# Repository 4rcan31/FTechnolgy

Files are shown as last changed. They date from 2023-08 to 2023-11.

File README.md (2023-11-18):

# FTecnology
## _Empresa para tus mascotas_

Somos una empresa dedicada a proporcionar soluciones innovadoras para el cuidado y mantenimiento de mascotas. Nuestra primera solución destacada es **Croquette**, un dispensador de comida para mascotas que ofrece una experiencia única y conectada. Este repositorio contiene tanto información sobre el proyecto principal, FTecnology, como los detalles específicos de Croquette.

## FTecnology: Innovación en Cuidado de Mascotas (Croquette)
FTecnology es la empresa detrás de la solución Croquette. Nuestra misión es mejorar la vida de las mascotas y sus dueños a través de soluciones tecnológicas innovadoras. Estamos comprometidos con la excelencia en diseño, funcionalidad y experiencia del usuario.

# Croquette
Croquette es un dispensador de comida para mascotas que va más allá de lo convencional. Su característica principal es la capacidad de conectarse a la aplicación de FTecnology, lo que permite a los dueños de mascotas dispensar comida de manera remota a través de Internet. Esto proporciona flexibilidad y comodidad tanto para los dueños de mascotas como para las propias mascotas.
## Features

- **Conexión Remota:** Croquette se conecta a la aplicación FTecnology, lo que permite a los usuarios dispensar comida de forma remota. Ya no es necesario estar físicamente presente para alimentar a tu mascota.

- **Programación de Alimentación:** Los usuarios pueden establecer horarios de alimentación regulares para sus mascotas a través de la aplicación. Croquette dispensará automáticamente la cantidad programada de comida en los momentos designados.

- **Monitoreo en Tiempo Real:** La aplicación proporciona información en tiempo real sobre cuándo se dispensó comida por última vez, cuánta comida queda en el dispensador y el consumo de comida de tu mascota en general.

## Archivos de Diseño de Croquette
En este repositorio, encontrarás los archivos de diseño de Croquette (El dispensador) en formato .blend y .stl

# Documentación de Croquette
Si deseas ver la documentación de Croquette, haz click [aquí](/Croquette/README.md).

# Instalación

## Requisitos 
- Git.
- El comando `php` debe estar disponible en tu terminal (configura las variables de entorno en caso de usar Windows).
- PHP versión >= 7.
- MySQL debe estar instalado en tu sistema.
- El comando `mysql` debe ser accesible desde tu terminal (configura las variables de entorno en caso de Windows, o simplemente utiliza MySQL desde un gestor de bases de datos como phpMyAdmin o MySQL Workbench).
- Composer debe estar instalado (no es esencial, pero puede ser útil para la actualización de dependencias).
- Node.js es necesario para ejecutar el servidor de comunicación de Croquette.

## Recomendaciones (Solo en caso de que no estés seguro de lo que estás haciendo, o para evitar perder tiempo solucionando problemas de compatibilidad)

Una de las cosas necesarias es tener una versión de PHP igual o superior a 7. Si estás utilizando XAMPP, verifica que la versión sea la correcta, ya que XAMPP suele instalar `php v 5`. Yo recomiendo utilizar Laragon, ya que incluye una versión más actualizada de PHP y también MySQL (recuerda que debes editar la variable PATH para que los comandos `php` y `mysql` sean reconocidos). (Si no quieres hacer tanto tramite y instalar Laragon, primero verifica si tu XAMPP ya tiene una version de php mayor o igual que 7).Yo te recomendaría verificar primero tu versión de PHP antes de instalar Laragon o actualizar la versión de PHP en XAMPP.

Si deseas verificar tu versión de PHP (una vez hayas configurado la variable PATH), ejecuta:
```sh
php -v
```

No es estrictamente necesario configurar `mysql` o `php` en las variables de entorno (PATH) si no te sientes cómodo haciéndolo y si sabes lo que haces. En lugar de eso, puedes seguir estos pasos alternativos:

- **Configuración de MySQL:** Puedes utilizar la interfaz de usuario de tu gestor de bases de datos, ya sea phpMyAdmin o MySQL Workbench, para realizar el paso número 2, que implica crear la base de datos. Esto te permite hacerlo de manera gráfica y sin necesidad de configurar variables de entorno.

- **Configuración de PHP:** No es imprescindible tener PHP configurado en las variables de entorno. La única condición es que debes iniciar el servidor desde la carpeta `/public`. Esto se logra automáticamente con el comando `php jenu serve`, que ejecuta internamente `php -S 127.0.0.1:8080 -t /public`. Esta opción simplifica el proceso y no requiere ajustes complicados.

## Pasos
### 1. Clonar el repositorio
```sh
git clone https://github.com/4rcan31/FTechnology.git
```

### 2. Crear la base de datos
#### 2.1 Ingresar al gestor de base de datos
```sh
mysql -u root -p
```
El parámetro `-u` es para el usuario y `-p` para la contraseña.

#### 2.2 Crear la base de datos
```sql
CREATE DATABASE ftechnology;
```

### 3. Configurar variables de entorno (Archivo `.ENV`)

```env
DB_CONNECTION=mysql
DB_HOST=localhost
DB_PORT=3306
DB_DATABASE=ftechnology
DB_USERNAME=root
DB_PASSWORD=
```

##### Valores por defecto (generalmente no cambian)
- `DB_CONNECTION`: Gestor al que se conectará.
- `DB_HOST`: Host al que se conectará.
- `DB_PORT`: Puerto del host al que se conectará.

##### Valores que generalmente cambian
- `DB_DATABASE`: Nombre de la base de datos a la que se conectará.
- `DB_USERNAME`: Nombre de usuario para acceder al gestor de base de datos.
- `DB_PASSWORD`: Contraseña para acceder al gestor de base de datos (por defecto es vacía).

### 4. Verificar si la configuración de la base de datos fue exitosa

```sh
php jenu check:connection:mysql
```

### 5. Ejecutar las migraciones (crear tablas)

```sh
php jenu execute:migrations
```

### 6. Instalar las dependencias ejecutando
```sh
composer install
```
Este comando no es necesario (solamente para una posible actualizacion de las dependencias)

### 7. Ejecutar el servidor web
```sh
php jenu serve
```

El programa debería estar en funcionamiento en:
```sh
http://localhost:8080
```

# Instalación del Servidor Croquette

El servidor Croquette es una parte opcional de la aplicación que permite la comunicación en tiempo real con clientes de socket TCP (Croquettes). Para habilitar esta función, es necesario contar con Node.js, ya que el servidor utiliza un socket TCP implementado con la biblioteca "net" de Node.js. Este protocolo permite la comunicación bidireccional entre los clientes de socket TCP y la aplicación HTTP. A continuación, se describe el flujo de comunicación:

## Comunicación desde el Cliente de Socket TCP al Servidor Croquette (SocketServerCroquette) y la Aplicación HTTP (AppHttp)
### Cliente Socket TCP -> Socket Server Croquette -> Aplicación HTTP

1. Un cliente de socket TCP se conecta al servidor de Croquette (SocketServerCroquette).

2. El servidor de Croquette identifica la conexión como un cliente de socket TCP mediante una cabecera especial.

3. El servidor de Croquette guarda la conexión en un mapa de JavaScript asociándola con un token proporcionado por el cliente de socket TCP. El mapa se estructura de la siguiente manera:

   ```
   token -> socket
   ```

4. El servidor de Croquette realiza una solicitud HTTP (usando Axios) a la aplicación HTTP, incluyendo el token de identificación del cliente de socket TCP. Este token sirve como identificador del socket del cliente TCP para permitir la comunicación en tiempo real, ya que el socket del cliente TCP permanece activo en el mapa de conexiones.

## Comunicación desde la Aplicación HTTP (AppHttp) al Servidor de Croquette (SocketServerCroquette) y el Cliente de Socket TCP
### Aplicación HTTP -> Server Croquette -> Cliente Socket TCP

Cuando la aplicación HTTP desea enviar un mensaje al cliente de socket TCP, sigue el siguiente proceso:

1. La aplicación HTTP se conecta al servidor de Croquette TCP (SocketServerCroquette).

2. El servidor de Croquette (SocketServerCroquette) identifica si la entidad que se está conectando es la propia aplicación HTTP o un cliente de socket TCP mediante una cabecera especial.

3. Durante la misma conexión, la aplicación HTTP proporciona el token al servidor de Croquette (SocketServerCroquette) para indicar a quién se debe dirigir el mensaje.

4. El servidor de Croquette (SocketServerCroquette) verifica si el token está presente en su mapa de conexiones. Si se encuentra, se utiliza para enviar el mensaje a través del socket asociado a ese token.

Este flujo permite la comunicación en tiempo real entre la aplicación HTTP y los clientes de socket TCP a través del servidor de Croquette.

No necesitas realizar una instalación adicional, ya que las dependencias se descargaron automáticamente junto con el repositorio. Sin embargo, si deseas actualizarlas, puedes ejecutar alguno de los siguientes comandos:

Para instalar las dependencias:
```sh
npm install
```
Para actualizarlas:
```
npm update
```
Ambas opciones están disponibles para mantener tus dependencias al día.
## Ejecución del Servidor Croquette

Para iniciar el servidor Croquette, utiliza el siguiente comando:

```sh
node Server/Croquette.js
```

El servidor estará disponible en la siguiente dirección:

```sh
127.0.0.1:8081
```

Si deseas realizar pruebas, se proporciona una simulación de conexión de un Croquette que está asociado al primer Croquette Auth en la base de datos. Para iniciar la simulación de conexión, ejecuta el siguiente comando:

```sh
node Server/clienteSimulation.js 127.0.0.1 8081
```

La simulación de conexión para pruebas debería estar funcionando correctamente.

# Comandos FTecnology
FTecnology aún no cuenta con una interfaz gráfica para un panel de administración del CEO, pero sí cuenta con un CLI para ello, y hay algunos comandos que me han resultado útiles. Para ver los comandos de FTecnology, simplemente ejecuta:
```sh
php jenu help
```

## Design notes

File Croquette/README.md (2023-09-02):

# Croquette
Croquette es un dispensador de comida para mascotas que va más allá de lo convencional. Su característica principal es la capacidad de conectarse a la aplicación de FTecnology, lo que permite a los dueños de mascotas dispensar comida de manera remota a través de Internet. Esto proporciona flexibilidad y comodidad tanto para los dueños de mascotas como para las propias mascotas.
## Features

- **Conexión Remota:** Croquette se conecta a la aplicación FTecnology, lo que permite a los usuarios dispensar comida de forma remota. Ya no es necesario estar físicamente presente para alimentar a tu mascota.

- **Programación de Alimentación:** Los usuarios pueden establecer horarios de alimentación regulares para sus mascotas a través de la aplicación. Croquette dispensará automáticamente la cantidad programada de comida en los momentos designados.

- **Monitoreo en Tiempo Real:** La aplicación proporciona información en tiempo real sobre cuándo se dispensó comida por última vez, cuánta comida queda en el dispensador y el consumo de comida de tu mascota en general.

## Archivos de Diseño de Croquette
En este repositorio, encontrarás los archivos de diseño de Croquette (El dispensador) en formato .blend y .stl

### **Croquette/designs.tls/allDesing.stl  Croquette/designs.tls/allDesing.blend**
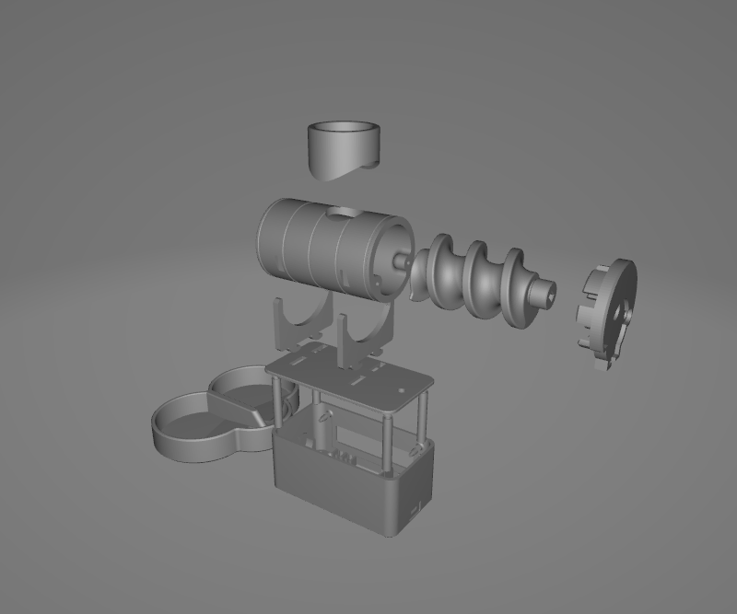
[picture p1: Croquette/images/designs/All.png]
AllDesingns


Explicación de diseño 

- **Líneas Celeste:** Explican el movimiento para ensamblar el dispensador
- **Líneas Rojas:** Las partes del dispensador
- **Líneas Verdes:** Entrada y salida de comida
- **Líneas Azules:** Dimensión de la imagen

### **Dimensión en menos X (-x)**
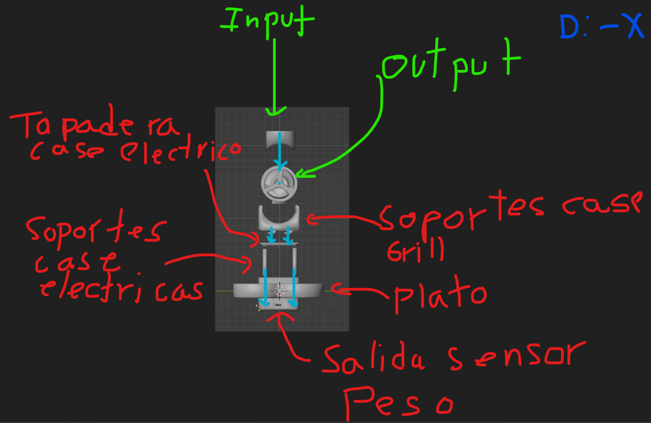
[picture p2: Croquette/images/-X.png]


### **Dimensión en X (x)**
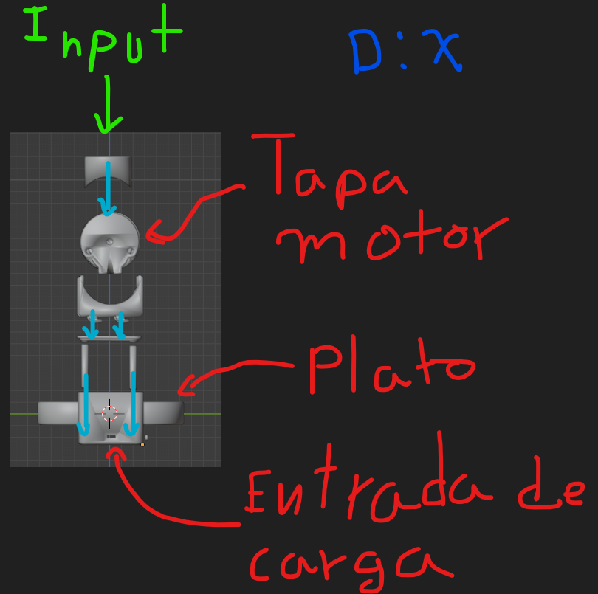
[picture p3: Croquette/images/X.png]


### **Dimensión en Y (Y)**
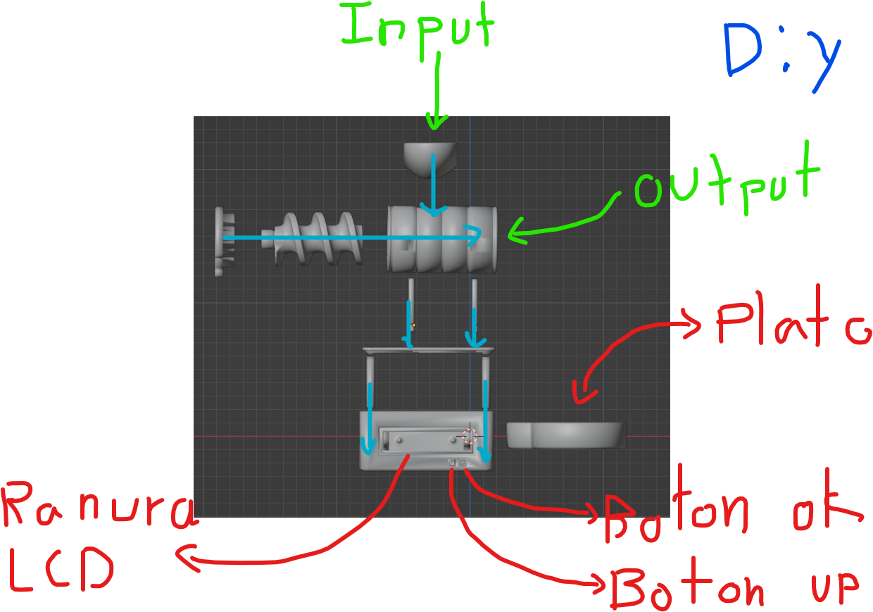
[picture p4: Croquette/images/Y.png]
ImageTechY


### **Dimensión en menos Y (-Y)**
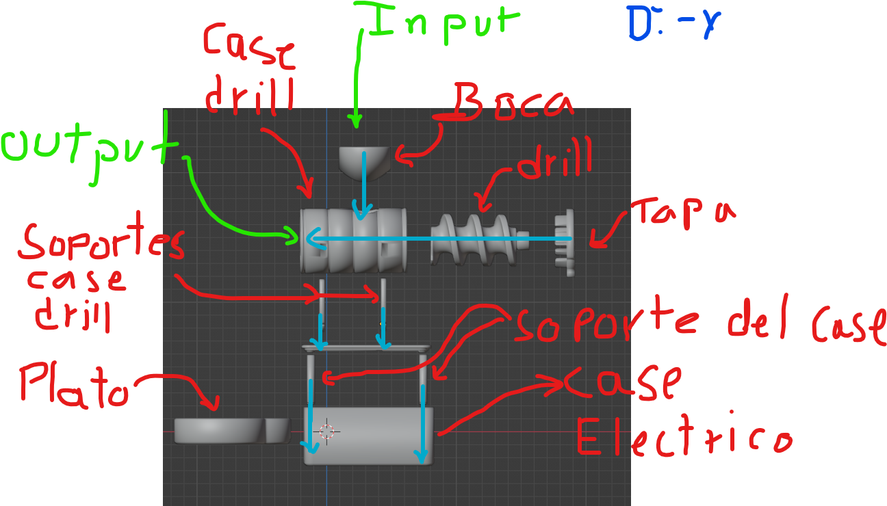
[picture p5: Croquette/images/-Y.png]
ImageTech-Y


### **Costado de todo el diseño**
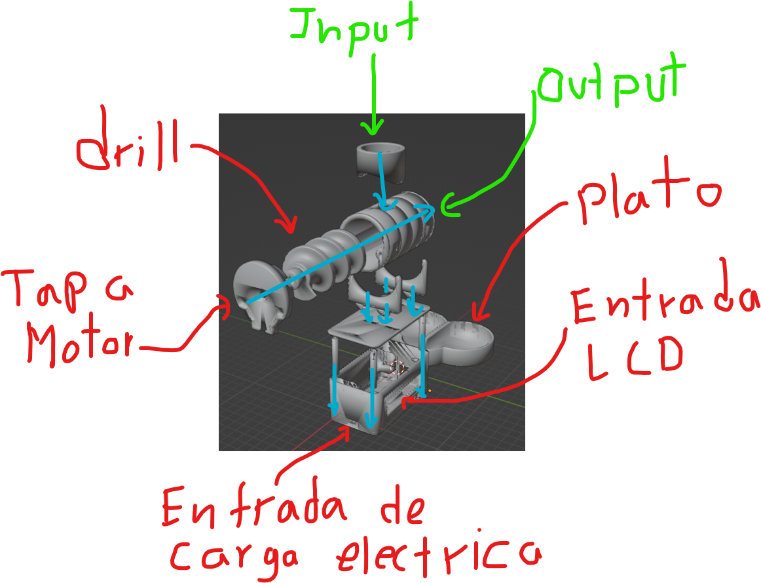
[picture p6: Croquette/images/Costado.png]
ImageTechAll

### **Case eléctrico**
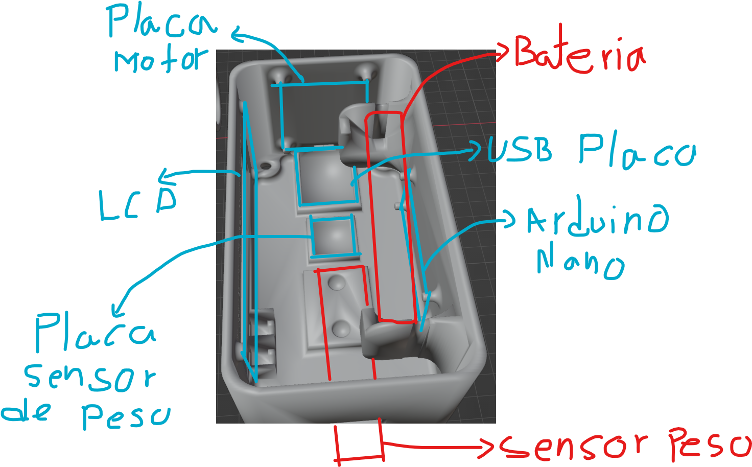
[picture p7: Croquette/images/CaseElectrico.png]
ImageTechCaseElectric


### **Soporte y botones del case**
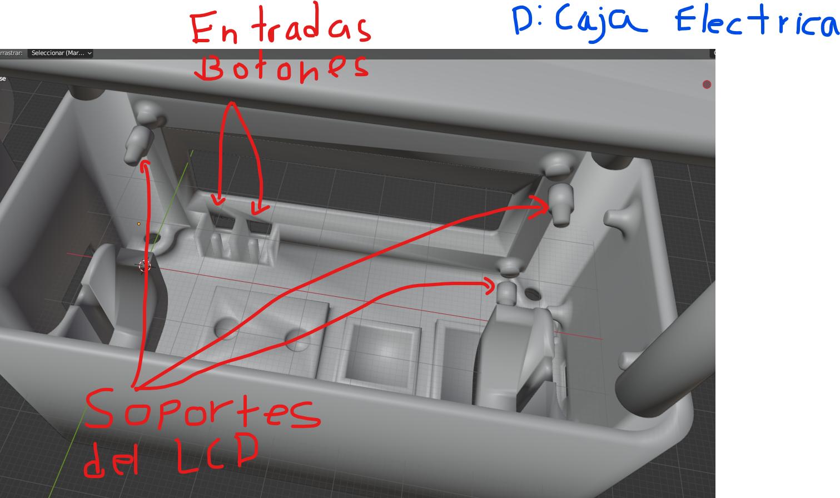
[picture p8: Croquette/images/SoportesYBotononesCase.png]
ImageTechSoporteAndButtons


## Tech

Estos son todos los archivos .tls en el proyecto para imprimir

- **Croquette/designs.tls/Button_Ok.tls** Es el botón de OK 
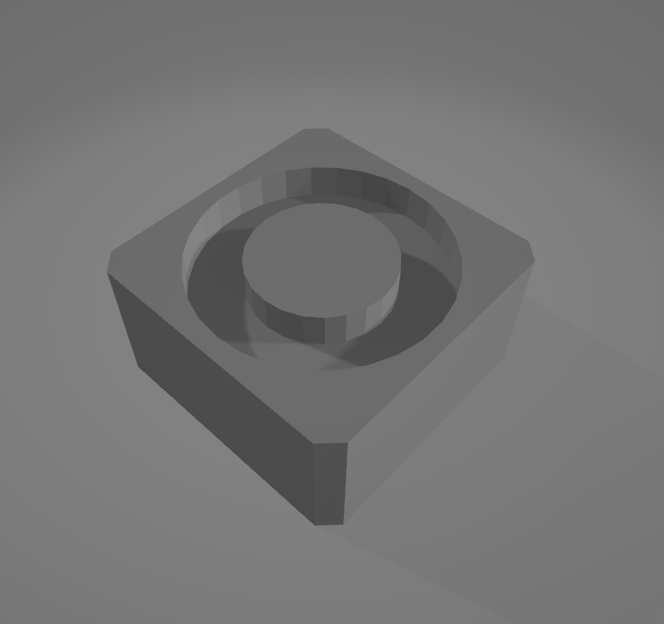
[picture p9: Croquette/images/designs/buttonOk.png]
ButtonOk

- **Croquette/designs.tls/Button_Up.tls** Es el botón para subir o bajar selecciones
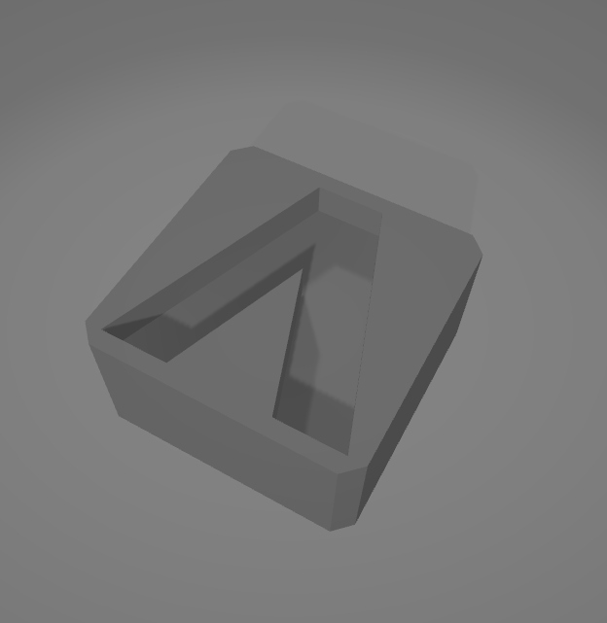
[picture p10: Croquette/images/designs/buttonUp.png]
ButtonUp

- **Croquette/designs.tls/Case_Cover_Leg.tls** Soporte de caja eléctrica (x4)
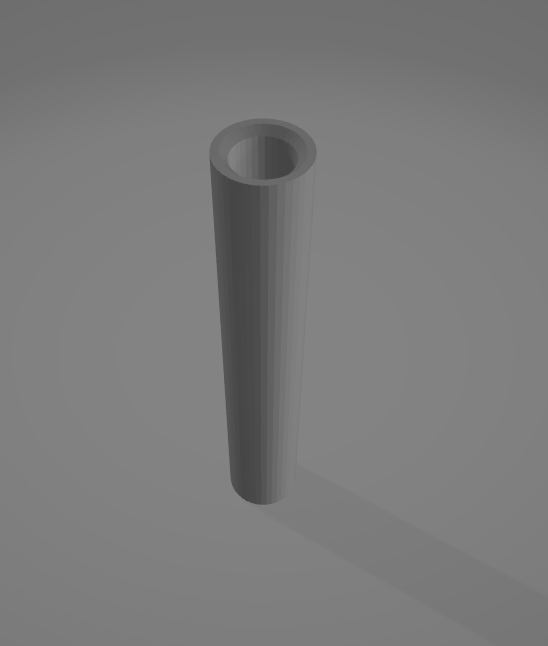
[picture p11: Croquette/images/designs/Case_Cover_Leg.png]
LegCasex4


```
Nota: El archivo Case_Cover_Leg.tls se imprimirá 4 veces, ya que son 4 soportes para la caja (en cada esquina un soporte) 
```
- **Croquette/designs.tls/Extruder_P1.tls** Este es el case para el espiral
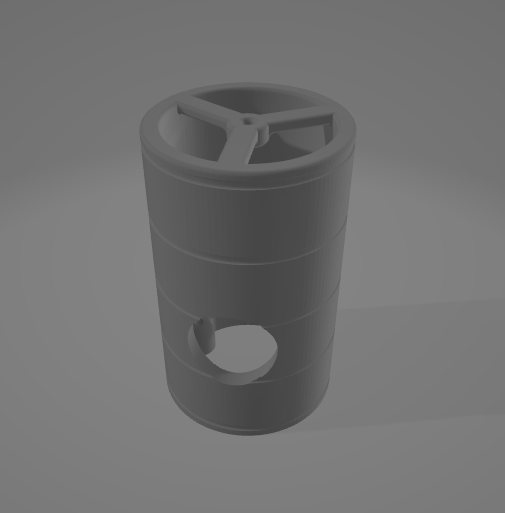
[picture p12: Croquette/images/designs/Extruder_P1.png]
CaseDrill

- **Croquette/designs.tls/Extruder_P2.tls** Esta pieza es donde entra la comida
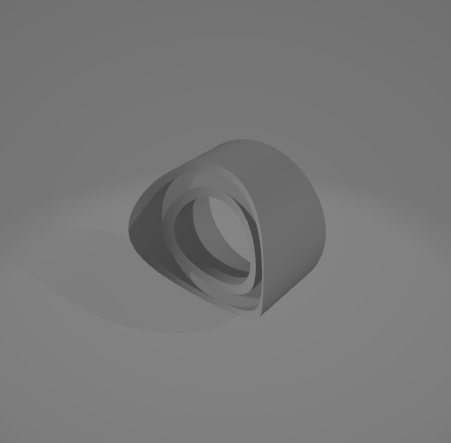
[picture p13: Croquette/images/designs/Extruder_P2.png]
TopCaseDrill

- **Croquette/designs.tls/UNO+PW_Case.tls** Este es el case eléctrico
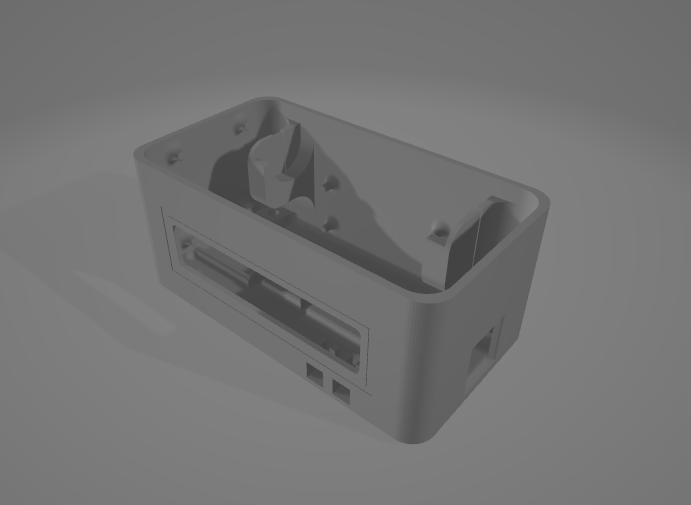
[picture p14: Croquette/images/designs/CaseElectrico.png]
CaseElectrico

- **Croquette/designs.tls/UNO+PW_Case.tls** La tapadera del case eléctrico
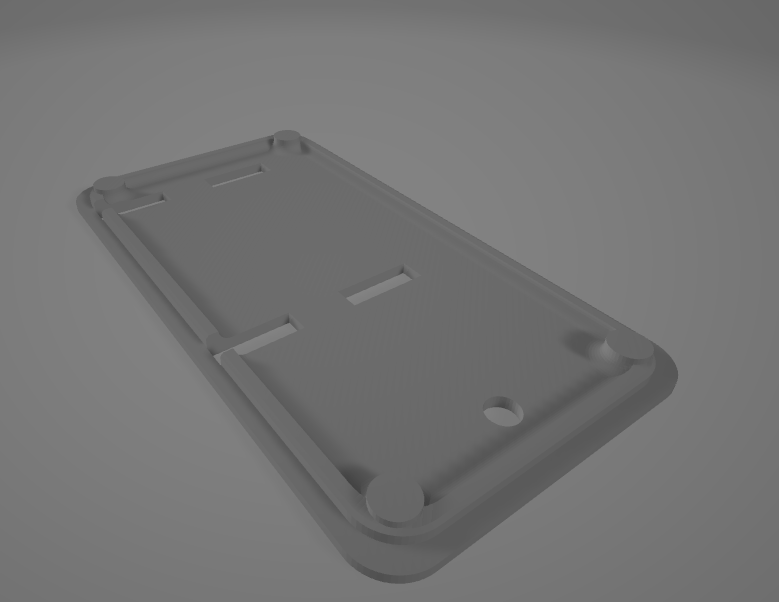
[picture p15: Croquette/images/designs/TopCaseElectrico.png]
CaseElectrico


- **Croquette/designs.tls/Tray.tls** EL plato donde se dispensara la comida
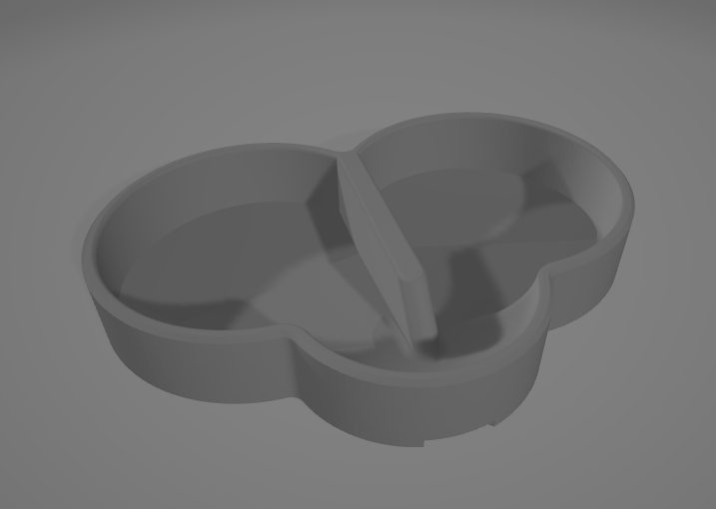
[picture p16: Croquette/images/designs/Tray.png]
Tray


- **Croquette/designs.tls/Tray_Left.tls** Plato del lado izquierdo
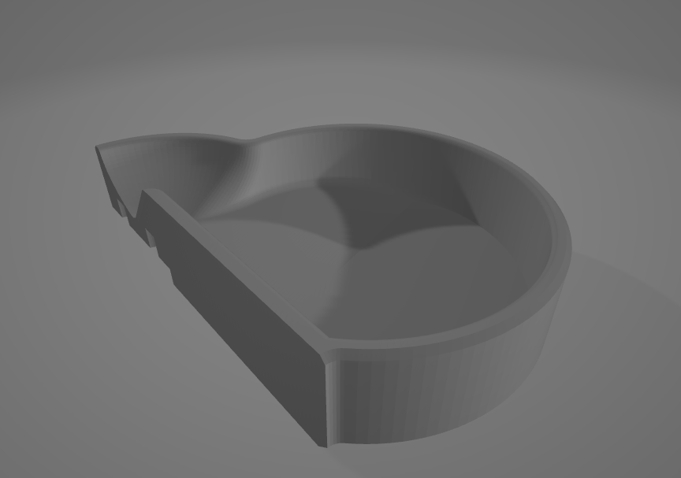
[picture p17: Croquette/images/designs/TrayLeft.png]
Tray


- **Croquette/designs.tls/Tray_Right.tls** Plato del lado Derecho
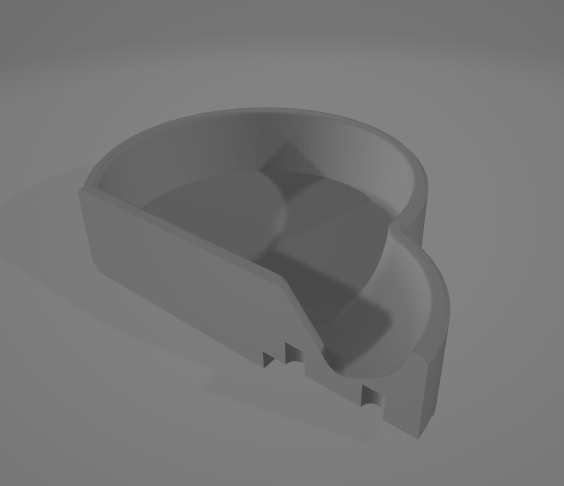
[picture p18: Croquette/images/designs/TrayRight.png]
Tray


```
Nota: Hay 3 archivos para el plato: Tray_left.tls, Tray_Right.tls & Tray.tls

Se imprimirá solo Tray.tls, ya que el de izquierda y derecha no son ensamblables
```

- **Croquette/designs.tls/LCD_Pin.tls** Pines para sostener la pantalla LCD (x3)
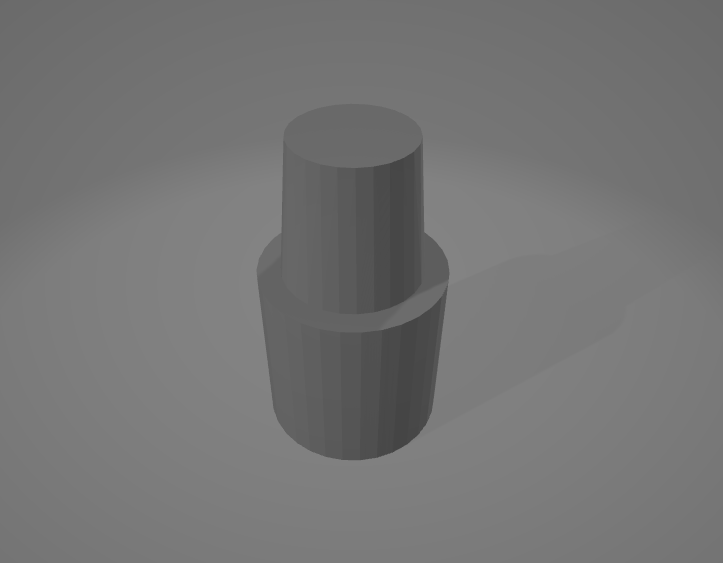
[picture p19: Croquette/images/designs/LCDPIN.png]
pinx3

```
Nota: El archivo LCD_Pin.tls se imprimirá 3 veces, ya que son 3 soportes para la pantalla LCD
```

- **Croquette/designs.tls/Motor_plate.tls** Placa para sujetar el motor y hacer girar el espiral
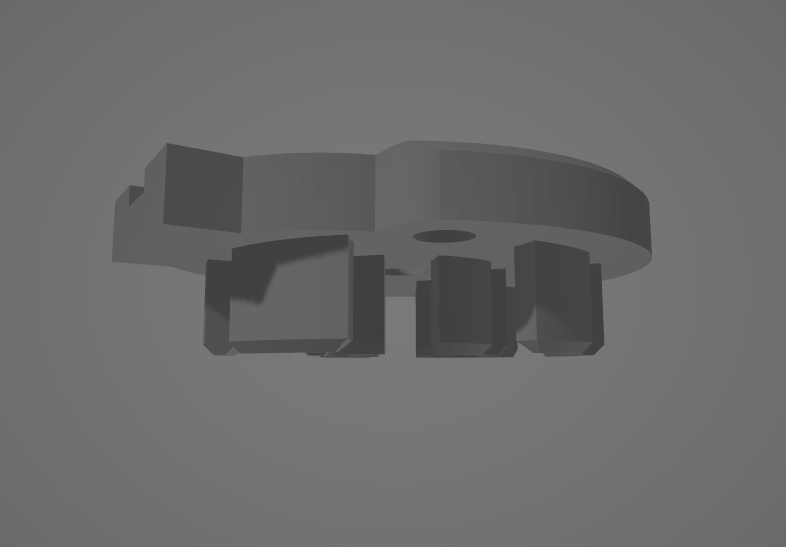
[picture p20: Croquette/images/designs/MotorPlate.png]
plateMotor


- **Croquette/designs.tls/Support_Feeder.tls** Soporte para mantener la case del espiral (x2)
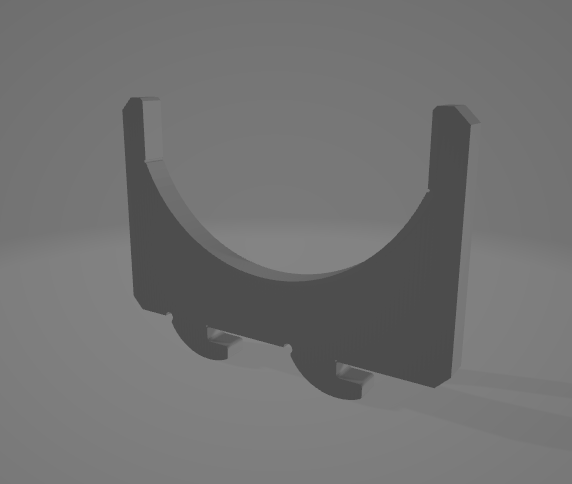
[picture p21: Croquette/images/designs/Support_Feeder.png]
SupporteCaseDrill

```
Nota: El archivo Support_Feeder.tls se imprimira 2 veces, ya que son 2 soportes para el case del espiral
```
- **Croquette/designs.tls/Wormgear.tls** Espiral normal (a imprimir)
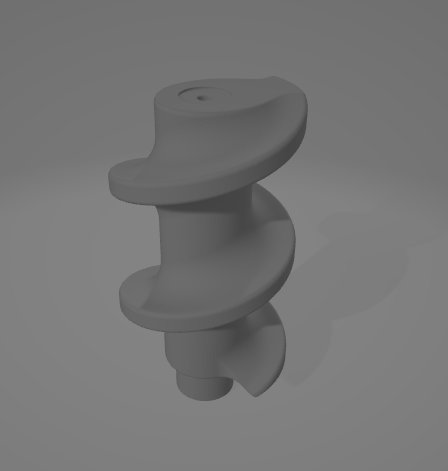
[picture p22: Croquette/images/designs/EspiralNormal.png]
DrillNormal


- **Croquette/designs.tls/Wormgear_short_pitch.tls** Espiral con un espacio mas largo 
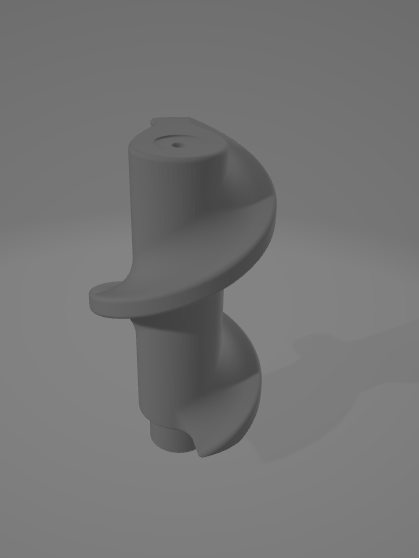
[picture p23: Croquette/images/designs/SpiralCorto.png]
DrillShort


- **Croquette/designs.tls/Wormgear_long_pitch.tls** Espiral con un espacio mas corto 
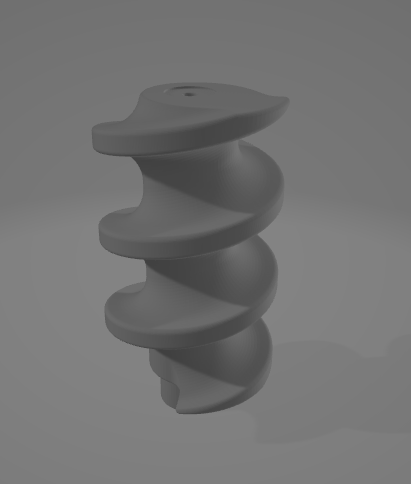
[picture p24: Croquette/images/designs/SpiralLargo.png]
DrillLong


```
Nota: Hay 3 archivos para el espiral: Wormgear.tls, Wormgear_short_pitch.tls & Wormgear_long_pitch.tls

Se imprimirá solamente uno, creería que el mas optimo es Wormgear.tls
```

### Resumen
- El archivo **Case_Cover_Leg.tls** se imprimirá 4 veces
- El archivo **Tray.tls** es el que se imprimirá 
- El archivo **LCD_Pin.tls** se imprimirá 3 veces
- El archivo **Support_Feeder.tls** se imprimirá 2 veces
- Por optimización, se imprimirá solamente el archivo **Wormgear.tls**

# Componentes electricos
- 1x Arduino Nano V3
- 1x Stepper Motor: 28BYJ-48; Driver: ULN2003A
- 1x Load Cell 1Kg with ADC HX711
- 1x LCD Display: LCD1602A
- 2x Tact button
- 1x Micro USB 1A 18650 Lithium Battery Charging Board
- 1x 18650 battery
- 1x Capacitor 330uF 35V 
- 2x M3x10 Screws (motor plate)
- 4x M4x10 Screws (case)
- 2x M4x15 Screws (load cell_tray)
- 2x M5x15 Screws (case_load cell)
- Cables

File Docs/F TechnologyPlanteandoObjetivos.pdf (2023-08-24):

Nombre del proyecto: F Technology | Fecha: Jueves 23 de febrero de 2023

Nombre de los integrantes:

1. Judith Cruz Palacios
2. Yara Stefanie Linares Hernández
3. Gabriela María Mejía Recinos
4. Gracia María González Méndez
5. Rodrigo Daniel Franco Escobar
6. Noe Antonio Molina López
- Objetivo general del Proyecto:

Desarrollar un producto que sea capaz de conectar al usuario con su mascota y brindarle cuidados alimenticios a distancia vía wifi.

- Área de Desarrollo del proyecto:
Informática
Comercio
Negocios
Bienestar animal
Hogar
- Necesidad que cubre o problema que solventa su proyecto:
Comunicación entre el dueño y su mascota.
La problemática alimentaria que se genera entorno a una necesidad básica que presente una mascota al estar solo.
- Materiales para utilizar: (hacer una tabla de cantidad, descripción, valor unitario y valor total)
Materiales | Cantidad | Valor unitario
Arduino Uno (con WiFi) | 1 | $55.00
Placa de presión | 1
Micro Servomotor MG90S | 1 | $14.98
Juego de 80 cables | 1 | $4.49
Sensor de ultrasonidos | 1 | $4.75
Filamento | 1 | $40.85
Comida para perros (usar para el prototipo) | 1 lb | $1.50
Comida para gatos (usar para el prototipo) | 1 lb | $1.50

- Público objetivo o clientes potenciales:
Personas que vivan solas, tengan mascotas y que mayor parte del tiempo estén fuera de casa.
- Descripción del funcionamiento paso a paso:
Un dispensador de comida conserva el alimento de la mascota en adecuadas condiciones. Planteado esto, el dispensador de comida contará con una programación que permite al usuario plantear periodos de tiempo en los que la comida será depositada en el recipiente a través de una aplicación y también el producto contara con un sensor en la parte inferior en donde se sirva la comida, este permitirá conocer si el plato está vacío; si detecta que no está vacío que se salte el horario siguiente pero si detecta que está vacío que llené el depósito, es decir, que el cliente podrá alimentar a su mascota sin la necesidad de estar en casa. Dicho esto, se realizaría de la siguiente manera:
- El dueño contara con una aplicación llamada F technology, donde realizara las solicitudes de registro necesarias para su ingreso en dicha App.
- Al ingresar el usuario marcara los lapsos de tiempo y raciones en los que desea que se sirva la comida.
- Dicha información será transmitida vía wifi al arduino incluido en el producto, que con la programación adecuada realizará cada una de las solicitudes propuestas.
- La comida será trasladada al recipiente por un tubo el cual tendrá una compuerta que abrirá y cerrará con la información transmitida al servomotor.
- Cuando el recipiente de alimento este vacío el arduino emitirá un mensaje a través de la aplicación al usuario. Logrando que el ciclo de alimentación se efectué de la misma manera planteada desde el punto 2.
- En el dado caso el sensor detecte que el recipiente aún no está vacío se saltará hasta el siguiente horario para servir la ración de alimento y dejará un registro en la aplicación para avisar al usuario cuando se efectuó un salto de horario.
- Diseño preliminar del proyecto (puede usar Tinkercad para ilustrarlo)



- La competencia:
- PUPPY KITTY 4L
- WellToBe
- SiSmart (Peet Feeder)
- Balimo Lena 4L
- PetKit
- Problemas encontrados:

Para la implementación del producto:
- Credencial de salubridad.
- Accesibilidad que el cliente tenga a una red. o Nivel de ingresos económicos del cliente.
- Creencias socioculturales del cliente.
- Soluciones posibles a los temas anteriores:
- Solicitud de credencial de salubridad.
- Cuando el cliente esté en el proceso de compra de producto será sometido a un cuestionario en el cual se le pregunte a cerca de la calidad de red de internet que posee
- Evaluar en base a formularios o cuestionarios el porcentaje de ingresos económicos, posteriormente moldear el producto al alcance de cada categoría socioeconómica.
- Realizar producciones beta o evidencias en exposición sobre el funcionamiento del producto.
- Necesidades futuras para el logro de concreción:

- Ingresos económicos
- Producción
- Línea de tiempo hasta el tercer periodo:

### 1. Buscar problemas en nuestra realidad o entorno

### 2. Lluvia de ideas para crear soluciones a los problemas encontrados haciendo uso de

arduino y el uso de la impresora 3D

### 3. Escogiendo ideas y analizarlas a fondo (aplicarles el FODA, el mapa de empatía y el

PEST)

### 4. Creando ideas para el logo y nombre del emprendimiento

### 5. Concretar a fondo cuales son las funciones que queremos que el producto realice 6. Comenzar con la creación de las primeras pantallas de la aplicación para el control

del producto (SplashScreen, Login, Menú)

### 7. Probando ideas para carcasa del producto y para poner la ubicación de la placa de

arduino
2 8. Hacer listado de materiales que se necesitan para crear la carcasa del producto
9. Empezar con la programación del producto por medio de C++
P 10. Desarrollo más a fondo de la programación de las pantallas de la aplicación
11. Creación del primer prototipo
12. Detectar posibles fallas.
13. Análisis de posibles mejoras a implementar.
14. Iniciar diseño de carcasa en impresora 3D.

1

P

3

P

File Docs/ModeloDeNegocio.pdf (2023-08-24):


# MODELO DE NEGOCIO FTECNOLOGY

## Contenido

Situación problemática | 2
Propuesta de negocio | 2
Modelo canvas | 4
Segmento de mercado | 5
Los jóvenes adultos (22-25) / demográfico | 5
Familia con hijos adolescentes / psicográfico | 5
Canales de distribución (tabla) | 0
Propuesta de valor | 0
Perfil del cliente | 0
Perfil de la empresa | 0
Presupuesto | 1
Producto material | 1
Presupuesto aplicación | 1
Integrantes | 2
Código de honor | 2

## Situación problemática

En la actualidad son con demasía los trabajos que requieren un mayor aporte presencial, por lo que la mayoría de la población salvadoreña invierte largos periodos de tiempo, muchas de estas personas involucradas han creado un lazo afectivo con sus fieles mascotas, brindándoles cariño y cuidados básicos que estos animales demanden. La responsabilidad, el compromiso, la lealtad y el amor incondicional forman parte de un vínculo afectivo que el dueño tiende a hacer con su mascota, por consecuencia se genera una empatía animal donde el individuo querrá brindarle cariño y cuidados básicos u específicos para el sano desarrollo y cuidado de su mascota.

En nuestro país existen muchas personas poseedoras de mascotas que pasan lejos de sus casas durante largos períodos de tiempo ya sea por factores académicos o laborales que demanden su presencia, por lo tanto, sus mascotas quedan solas en casa sin un control en su entrega diaria de alimento; debido a esto los dueños idean posibles soluciones como pedirle a un vecino o persona de confianza que pueda cuidarlo mientras no esté, cancelar o posponer salidas, dejar raciones dobles, etc., algunas de estas soluciones llegan a generar un desbalance en la ingesta de alimentos, por lo que, a largo plazo desarrollarían problemas de salud (vomito, sobrepeso, diarrea etc.), llegando a afectar así un desarrollo adecuado más, sin embargo, la mascota no es la única que tiene problemas en esta situación, al amo o dueño puede pasar por momentos de estrés o preocupación.

## Propuesta de negocio

Un dispensador de comida conserva el alimento de la mascota en adecuadas condiciones es por esto que F Technology con su producto Croquette planea funcionar como un dispensador de comida para mascotas que ayudará al cliente a organizar y/o crear horarios de alimentación para su mascota de forma remota. Pero indagaremos más en esto continuación.

Muchas personas tienen mascotas, solo en El Salvador, el 65% de la población admite tener al menos una mascota (predominando perros y gatos); a su vez, dentro de este gran porcentaje de personas con mascotas se encuentra un grupo que no tiene tiempo (ya sea porque estudia, trabaja o realizaba ambas actividades) que dedicarles a sus mascotas, en especial a uno de los puntos más importantes del cuido de una “la alimentación”. De este problema ya se han intentado encargar otros productos como “Smell n Smile”, “Ferplast”, entre otros; pero todos estos fallan en algo, su funcionamiento, pues sirven comida de forma “constante” o tras presionar un botón colocado en el dispensador, por lo tanto, una persona que no se encuentra cerca de dicho dispositivo y por ende de su mascota, no puede llevar registro de las porciones que esta come.

Ahora la pregunto es, ¿cómo Croquette resuelve este problema? Bien, conocemos el problema y sabemos que no todas las mascotas son iguales o comen la misma cantidad de alimento, es por esto que nuestro producto funciona como un dispensador de comida, pero lo que caracteriza a Croquette es que no es un dispensador de comida cualquiera, Croquette permite al usuario programar la hora y tamaño de porción que se servirá y todo esto de forma remota, haciendo uso de una aplicación móvil llamada FTechnology que es amigable al usuario y realmente intuitiva, todo esto permite llevar control de la alimentación de la mascota.

El objetivo del producto no es solo ser comprado, sino funcionar como servicio; esto gracias a la aplicación móvil (indispensable para el uso del dispositivo), ¿por qué hablamos de un servicio? Bien, primero se debe saber que dentro de esta app se planea generar ingresos mediante publicidad, dicha publicidad podrá ser bloqueada por el usuario tras pagar una cuota mensual, trimestral o anual, además de que el simple hecho de poseer la aplicación le dará acceso a cualquier actualización de la misma. Así que el objetivo del producto es ser comprado, pero hacer que el usuario no se separe de la compañía.

Ahora bien, ¿cómo funciona Croquette? El dispensador de comida contará con una programación que permite al usuario plantear periodos de tiempo en los que la comida será depositada en el recipiente a través de una aplicación, asimismo el producto contará con un sensor en la parte inferior del plato de comida, este permitirá conocer si el plato está vacío o no; los materiales del dispensador son aluminio (el recipiente de comida) y plástico (la carcasa del producto).

Dicho esto, se realizaría de la siguiente manera:

- El dueño contará con una aplicación llamada “F Technology”, donde realizará las solicitudes de registro necesarias para su ingreso en dicha App.
- Al ingresar el usuario marcará los lapsos de tiempo y raciones en los que desea que se sirva la comida.
- Dicha información será transmitida vía wifi al Arduino incluido en el producto, que con la programación adecuada ejecutará cada una de las solicitudes propuestas.
- La comida será trasladada al recipiente por un tubo, el cual tendrá una compuerta que abrirá y cerrará con la información transmitida al servomotor.
- Cuando el recipiente de alimento este vacío, el Arduino emitirá un mensaje a través de la aplicación al usuario. Logrando que el ciclo de alimentación se efectúe de la misma manera planteada desde el punto 2.
- En el dado caso el sensor detecté que el recipiente aún no está vacío, se saltará hasta el siguiente horario para servir la ración de alimento y dejará un registro en la aplicación para avisar al usuario cuando se efectuó un salto de horario

Para cerrar, Croquette es un producto que busca resolver una problemática que aqueja a un público muy amplio (como lo es el de personas con mascotas, pero poco tiempo libre) es por ello y porque sobresale y diferencia de otros muchos productos que buscan lo mismo, Croquette que es un producto viable para desarrollar y que no solo generara ingresos, sino ganancias.

## Modelo canvas


## Segmento de mercado

### Los jóvenes adultos (22-25) / demográfico

Porque son ellos quienes están más tiempo fuera de casa por diversas actividades, y por consecuencia no les dedican el debido tiempo a sus mascotas.

Ejemplo de este segmento sería Pedro

- 25 años
- Soltero
- Clase socioeconómica media
- Posee 2 mascotas (1 gato y 1 pitbull)
- Universitario con trabajo de medio tiempo
- Soltero
- Reside en la zona oriental, departamento de San Miguel
- Unas de sus mayores aficiones es leer libros y hacer escritos
- Métodos de compra habituales, por lo que tiende a adquirir productos personales y de cuidados para su mascota mediante redes sociales, especialmente Instagram

### Familia con hijos adolescentes / psicográfico

Mayormente en una familia con hijos (adolescentes) son quienes están y comparten mayor tiempo con las mascotas, ya que poseen mayor disponibilidad de tiempo, por lo que se genera un vínculo afectivo entre ellos.

Quienes poseen y administran los ingresos de la familia y gastos que sus hijos requieran son los padres o tutores.

Ejemplo de este segmento sería una familia de 3 integrantes

- Steven, padre de 43 años, contador
- Paola, madre de 39 años, maestra
- María, hija de 17 años, estudiante

Que poseen las siguientes características

- Clase socioeconómica media
- Poseen un perro mestizo
- Residen en la zona central, departamento San Salvador
- Una de las aficiones de la familia es compartir tiempo con los demás integrantes de su familia, por lo que en periodos de vacación realizan reuniones familiares en otros departamentos por periodos de tiempo medio.
- Los padres usualmente visitan tiendas por recomendaciones
- La hija tiende a cotizar productos en línea

## Canales de distribución (tabla)


## Propuesta de valor

### Perfil del cliente

- Actividades
- Alimentar una mascota
- Encontrar tiempo para alimentar una mascota.
- Encontrar una persona que alimente a una mascota cuando no se está en casa.
- Dolor
- Gastar dinero para alimentar una mascota (la acción de servir comida, se obvia el gasto en *comida*)
- Usar tiempo libre para alimentar una mascota.
- Ganancias
- Mascota feliz :)
- Dueño de mascota feliz :)
- Dinero y tiempo ahorrado (porque se hace una sola inversión)

### Perfil de la empresa

- Productos y servicios
- Dispensador de comida regulable.
- App para regular un dispensador de comida para mascotas.
- Aliviador de dificultades
- Manejo a larga distancia por medio de Internet.
- App dinámica y fácil de entender y manejar.
- Programación de horarios para servir la comida.
- Avisos cuando ya esté apunto d acabarse la comida y cuando se salta una ración de comida
- Ganancia
- Aliviado por saber que su mascota se alimenta bien.
- Felicidad por que la aplicación no es difícil de usar.
- Bienestar alimenticio de su mascota.
- Tener seguridad de que su mascota poseerá sus alimentos cuando se requiera
- Ahorrar tiempo en servirle la comida a su mascota
- Economizar la cantidad de concentrado que consume su mascota

## Presupuesto

### Producto material

### Presupuesto aplicación

Materiales | Cantidad | Valor
Hosting (servidor) | 1 | $3 por mes
Materiales Materiales | Cantidad Cantidad | Valor unitario Valor unitario
Arduino Uno (con Wifi) Arduino Uno (con Wifi) | 1 1 | $55.00 $55.00
Placa de presión/ piezoeléctrico/sensor HX711/ Placa de presión/ piezoeléctrico/sensor HX711/ sensor de fuerza MF01 sensor de fuerza MF01 | 1 1 | $44.98/$3.99/$4.99/$8.89 $44.98/$3.99/$4.99/$8.89
Micro Servomotor MG90S/ Motor CC Micro Servomotor MG90S/ Motor CC | 2 2 | $14.98/$10.56 $14.98/$10.56
Juego de 80 cables Juego de 80 cables | 1 1 | $4.49 $4.49
Sensor de ultrasonidos Sensor de ultrasonidos | 1 1 | $4.75 $4.75
Filamento Filamento | 1 1 | $40.85 $40.85
Comida para gatos (usar para el prototipo) | 1 lb | $1.50
Juego de 40 ventosas de plástico con 4 diámetros: 0.787 in, 1.181 in, 1.575 in, 1.969 in | 1 | $12.77
Display LCD 16 x 2 | 1 | $5.54
Potenciómetro | 1 | $0.52
Resistencias de 330 Ohmios | 2 | $0.35
Resistencia de 4.70 Kohmios | 1 | $0.19
Transistor | 1 | $0.23
Batería de 9 voltios recargable | 1 | $6.50

## Integrantes

1. Judith Cruz Palacios
2. Yara Stefanie Linares Hernández
3. Gabriela María Mejía Recinos
4. Gracia María González Méndez
5. Rodrigo Daniel Franco Escobar
6. Noé Antonio Molina López

## Código de honor

" I have not given or received any kind of unauthorized aid."

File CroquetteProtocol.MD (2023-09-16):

# Croquette Protocol

Este es un nuevo protocolo para conecctarse

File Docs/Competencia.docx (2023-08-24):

COMPETENCIA

ARF Pets

Arf Pets es una empresa que se especializa en productos y accesorios para mascotas. Ofrecen una amplia gama de productos que incluyen camas para mascotas, jaulas, puertas para mascotas, juguetes interactivos y dispensadores de alimentos, entre otros.

Descripción: Uno de los productos más populares de Arf Pets es su línea de alimentadores automáticos para mascotas. Estos alimentadores permiten programar y controlar las porciones de comida que se sirven a las mascotas, lo que resulta útil para mantener una dieta regular y controlada. Algunos de los alimentadores también cuentan con funciones adicionales, como grabar mensajes de voz para llamar a las mascotas a la hora de comer.

Precio: 60$

Función: Hasta 4 comidas programables (también el tamaño de las mismas), grabadora de voz y alarma al servir, funciona con baterías o mediante CD

Segmento de mercado: Adultos y jóvenes adultos, Arf Pets utiliza diversos canales de redes sociales, como Twitter, Facebook e Instagram, para interactuar con su audiencia. En estas plataformas, realizan sorteos y concursos, brindando la oportunidad a los seguidores de ganar premios. Además, publican contenido relevante y entretenido, como memes y tendencias de moda, que resuenan especialmente entre el público joven y adulto. Así mismo, ARFPets se dirige a propietarios de mascotas que buscan productos de alta calidad y confianza para el cuidado y bienestar de sus animales.

¿Por qué ARFPets es nuestra competencia?

ARFPets es una competencia debido a su enfoque en la calidad de los productos que ofrecen, a la variedad de su oferta, su enfoque en la comodidad y calidad de vida, así como su reputación y confianza ganada entre los propietarios de mascotas.

Petlibro

Petlibro es una marca especializada en productos y tecnología para mascotas. Se enfocan en crear productos innovadores y de alta calidad para mejorar la vida y el bienestar de las mascotas y sus dueños.

Descripción: Uno de los productos destacados de Petlibro es su línea de comederos automáticos para mascotas. Estos comederos cuentan con características avanzadas, como programación de horarios de alimentación, porciones controladas y alimentación precisa. Los comederos automáticos de Petlibro ofrecen conveniencia y ayudan a mantener una dieta saludable y regular para las mascotas.

Precio: $51.99 a $159.99

Segmento de mercado: Petlibro tiene como objetivo principal atraer a los jóvenes y los millennials, quienes son altamente activos en la participación de sorteos y regalos a través de aplicaciones populares entre los jóvenes adultos y la Generación Z. Esta estrategia les permite promocionar tanto su marca como sus productos de manera efectiva. Además, Petlibro también se dirige a propietarios de mascotas que buscan soluciones innovadoras y tecnológicas para el cuidado y el bienestar de sus compañeros.

¿Por qué Petlibro es nuestra competencia?

Petlibro es una competencia debido a su enfoque en la innovación tecnológica, en la calidad de sus productos, a su enfoque en la salud y el bienestar de las mascotas, y la atención que brindan al cliente. Estos factores les permiten posicionarse como una opción atractiva para los propietarios de mascotas que buscan soluciones modernas y confiables para el cuidado de sus compañeros.

WORPET

WOPET es una marca que se especializa en la fabricación de productos y tecnología para mascotas, con un enfoque particular en alimentación automatizada y cuidado de mascotas.

Descripción: Uno de los productos más destacados de WOPET es su línea de comederos automáticos para mascotas. Estos comederos cuentan con funciones avanzadas, como programación de horarios de alimentación, porciones controladas y alimentación precisa. Algunos modelos incluso tienen capacidad de grabación de voz para llamar a las mascotas a la hora de comer. Estos comederos automáticos brindan comodidad y ayudan a mantener una dieta regular y equilibrada para las mascotas.

Precio: 60$

Función: se puede programar hora y tamaño de porciones, con un máximo de 6 raciones programables, además, contiene una grabadora de voz para luego usar una bocina, de esta forma se pueden dejar mensajes a las mascotas (10 segundos)

Segmento de mercado: Adultos propietarios de mascotas que buscan soluciones tecnológicas y automatizadas, WOPET se dirige a su público objetivo a través de canales estratégicos, como Facebook, reconociendo que esta plataforma es mayormente utilizada por adultos. Aprovechan este medio para darse a conocer y conectar con su audiencia. WORPET se dirige a un segmento de mercado que busca soluciones tecnológicas y prácticas para el cuidado de sus mascotas. Sus productos automatizados ofrecen comodidad, conveniencia y contribuyen al bienestar de las mascotas, satisfaciendo las necesidades y deseos de los propietarios modernos.

¿Por qué WORPET es nuestra competencia?

WOPET es una competencia para las nuevas marcas dirigidas a las mascotas debido a su reconocimiento de marca, experiencia en el mercado, por su gama de productos establecida y satisfacción brindada al cliente.

FTECHNOLOGY

Descripción

Croquette es una herramienta indispensable para aquellos que pasan mucho tiempo lejos de casa y tienen mascotas. Se trata de un dispensador de comida controlado a larga distancia que te permite programar horarios alimenticios, recibir notificaciones sobre la cantidad de comida servida y llevar un control automático de las porciones para tu mascota, todo desde la comodidad de una aplicación móvil. Con Croquette, puedes estar tranquilo sabiendo que tus fieles amigos siempre serán alimentados adecuadamente, ya que solo necesitas llenar el dispensador y dejar que Croquette se encargue del resto del día.

¿Cómo se destaca?

Para aquellos propietarios de mascotas que se enfrentan al desafío de estar lejos de casa durante largos períodos sin poder alimentar a sus compañeros de manera personal. Consciente de esta problemática, FTECHNOLOGY presenta "Croquette", un innovador dispensador de comida para mascotas controlado a través de Internet. Este dispositivo viene a satisfacer esa necesidad al garantizar que las mascotas reciban alimentación adecuada incluso en ausencia de sus dueños.

¿Qué diferencia a Croquette de la competencia?

A diferencia de otros dispensadores existentes en el mercado que utilizan cables USB, baterías o conexiones de red WiFi, Croquette va más allá al ser controlado a través de una aplicación conectada a Internet. Esta innovadora función permite establecer una conexión entre el propietario y su mascota, incluso a larga distancia, logrando así una conexión cercana y brindando tranquilidad al dueño sabiendo que puede cuidar y alimentar a su mascota sin importar dónde se encuentre.

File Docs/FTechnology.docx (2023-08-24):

FTechnolgy

Dispensador de comida para mascotas, controlado a distancia mediante una aplicación.

Integrantes

1. Gabriela María Mejía Recinos
2. Gracia María Gonzáles Méndez
3. Judith Cruz Palacios
4. Keren Abigail Guerrero López
5. Noé Antonio Molina López
6. Rodrigo Daniel Franco Escobar
7. Yara Stefanie Linares Hernández


“We have neither given nor received any unauthorized aid.”

Vista previa del formulario – Registrarse -


Vista preliminar del formulario – Registrarse -


Este formulario tiene como objetivo recopilar la información proporcionada por el usuario durante el proceso de registro. Utilizamos los siguientes elementos:

- Etiquetas (Labels) para identificar los campos a completar.
- Campos de texto (TextBox) para que el usuario ingrese sus respuestas.
- Un botón denominado "Registrarse" para confirmar, guardar y enviar la información solicitada.

Los datos recopilados se enviarán para su almacenamiento en una base de datos. Utilizamos Php para conectarnos a una base de datos conocida como MariaDB (anteriormente MySQL). Esta base de datos relacional (SQL) nos permite guardar datos en tablas con el objetivo de almacenar la información adquirida y preservarla para su uso en el futuro. Si el usuario ha mantenido una cuenta activa con FTechnology, puede acceder al formulario correspondiente haciendo clic en el texto resaltado en azul que dice "Iniciar Sesión".

Vista previa del formulario – Iniciar Sesión -


Vista preliminar del formulario – Iniciar Sesión -

Este formulario tiene como finalidad capturar la información que los usuarios ingresan durante el proceso de inicio de sesión en la página de FTechnology. Para lograrlo, se emplean los siguientes componentes:

- Etiquetas (Labels) para identificar los campos que deben completarse.
- Campos de texto (TextBox) que permiten a los usuarios ingresar sus respuestas.
- Un botón denominado "Iniciar Sesión" que cumple la función de confirmar, guardar y enviar la información proporcionada.

La información recopilada se enviará y almacenará en una base de datos. Utilizamos Php para establecer conexión con una base de datos llamada MariaDB (previamente conocida como MySQL). MariaDB es una base de datos relacional (SQL) que nos permite organizar los datos en tablas, con el propósito de preservar la información adquirida y mantenerla para su uso en el futuro. Si el usuario no recuerda haber mantenido una cuenta activa con FTechnology al intentar iniciar sesión, puede acceder al formulario correspondiente haciendo clic en el texto resaltado en azul que dice "Regístrate".

Vista previa del formulario – Contacto -


Vista preliminar del formulario – Contacto -


Este formulario tiene como objetivo recopilar la información que los usuarios ingresan al desear resolver inquietudes relacionadas con nuestros servicios y detalles de los productos. Para lograr esto, emplea los siguientes elementos:

- Etiquetas (Labels) para identificar los campos que deben ser completados.
- Campos de texto (TextBox) que permiten a los usuarios ingresar sus respuestas.
- Un botón denominado "Enviar" que tiene la función de confirmar y remitir las preguntas escritas por el usuario al correo oficial de la empresa.

La información recopilada se remitirá al correo oficial de FTechnology con el propósito de facilitar y mejorar la comunicación entre los usuarios y nuestros servicios.

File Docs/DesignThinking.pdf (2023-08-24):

# “Design Thinking”

Oportunidades, Fundacion Gloria de Kriete Emprendimiento P1
Ana Lucia Trinidad Gómez

Integrantes:
1. Judith Cruz Palacios
2. Yara Stefanie Linares Hernandez
3. Gracias María Gonzalez Mendez
4. Gabriela María Mejía Recinos
5. Rodrigo Daniel Franco Escobar
6. Noe Antonio Molina López

F Technology

Un dispensador de comida conserva el alimento de la mascota en adecuadas condiciones. Planteado esto, el dispensador de comida contará con una programación que permite al usuario plantear periodos de tiempo en los que la comida será depositada en el recipiente a través de una aplicación y también el producto contará con un sensor en la parte inferior en donde se sirva la comida, este permitirá conocer si el plato está vacío; si detecta que no está vacío que se salte el horario siguiente pero si detecta que está vacío que llené el depósito, es decir, que el cliente podrá alimentar a su mascota sin la necesidad de estar en casa. Dicho esto, se realizaría de la siguiente manera:
- El dueño contará con una aplicación llamada F technology, donde realizará las solicitudes de registro necesarias para su ingreso en dicha App.
- Al ingresar el usuario marcará los lapsos de tiempo y raciones en los que desea que se sirva la comida.
- Dicha información será transmitida vía wifi al arduino incluido en el producto, que con la programación adecuada realizará cada una de las solicitudes propuestas.
- La comida será trasladada al recipiente por un tubo el cual tendrá una compuerta que abrirá y cerrará con la información transmitida al servomotor.
- Cuando el recipiente de alimento esté vacío el arduino emitirá un mensaje a través de la aplicación al usuario. Logrando que el ciclo de alimentación se efectúe de la misma manera planteada desde el punto 2.
- En el dado caso el sensor detecte que el recipiente aún no está vacío se saltará hasta el siguiente horario para servir la ración de alimento y dejará un registro en la aplicación para avisar al usuario cuando se efectuó un salto de horario.

## DESIGN THINKING


### EMPATÍA

Mapa de empatía

Encuesta en Google Forms

https://docs.google.com/forms/d/e/1FAIpQLSdsR3Eo4c-o5tioHNsDi9w44DIcPA20TuHQPK5bVmClkoVxvA/viewf orm (https://docs.google.com/forms/d/e/1FAIpQLSdsR3Eo4c-o5tioHNsDi9w44DIcPA20TuHQPK5bVmClkoVxvA/viewform)



### DEFINICIÓN

Áreas de problemática y necesidades del cliente:

Darles de comer
1. Material del plato de comida (plástico, cerámica o metal)
2. Calidad de la comida
3. Obtención del alimento (precio, tipo y lugar de la compra)
4. Cuando la mascota come bota las croquetas del recipiente, es decir, le da vuelta al plato lo que provoca un desperdicio de comida.

Bañarlos
5. Ingredientes del producto de aseo (que no contengan químicos que pueden generar alergias o irritación)
6. Espacio adecuado para bañarlo, ya que algunos de los encuestados mencionaron que bañaban a sus mascotas en su patio esto generaba un desorden y, en algunos casos, lodo.

Dormirlos
7. Propietario de un espacio para dormir a la mascota, es decir, una cama.
8. Material o textura de las camas para mascotas.
9. Diseños originales

Control médico
10. Organización de un control de vacunas
11. Agenda de las citas al veterinario

### IDEAS

Debido a la encuesta realizada a el posible segmento de mercado, nos dimos cuenta que la problemática que más presentan los clientes es con respecto a la alimentación de sus mascotas, por lo tanto, decidimos centrar la lluvia de ideas en esa problemática.

1. Poner guardería para mascotas
2. Niñera de mascotas
3. Mini robot de comida
4. No tener mascotas
5. Dejarle doble ración de comida a la mascota
6. Salirse del trabajo para ir a darle alimento a la mascota
7. Dispensador de comidas de mascotas
8. Crear un plato con 4 divisiones las cuales se les abra la tapadera de acuerdo a la hora del día en que la mascota deba comer
9. Crear un área recreativa y de cuidado de mascotas en los lugares de trabajo de las personas
10. Entrenar a las mascotas para poder activar un botón que le brindará la comida cuando lo necesite
11. La creación de una máquina que cree materia comestible de concentrado de mascotas en base a desechos orgánicos

### PROTOTIPO


Descripción de su funcionamiento:


En este podemos observar el dispensador de comida en su totalidad, el embudo que dirige la comida hacía el plato y el mecanismo de bloqueo que se encuentra afuera del dispensador.

A la derecha podemos encontrar el mecanismo de bloqueo del dispensador. Este mecanismo hace uso de un motor cc, que al girar crea fricción con una banda en la puerta, haciendo que se mueva. Esta puerta se encuentra sostenida por dos rieles, que existen para mantener en su lugar la puerta y de esta forma evitar que caiga al suelo.

Arriba podemos ver el espacio de comida, el plato se encuentra debajo de la boca del embudo; es una cavidad rectangular con un sensor de fuerza MF01 cuya función es registrar fuerza. En este lugar, dentro de esta cavidad se coloca el plato, para que de esta forma al vaciarse/llenarse el sensor de fuerza MF01 registre los datos y los envié al arduino; consiguiendo así servir las porciones que el usuario quiere.

Se debe mencionar que debajo del embudo, es donde iría el arduino/placa, de ahí se alienta el motor cc, el sensor de fuerza MF01 y el display LCD 16 x 2.

### TESTEAR / EVALUAR

Cuestionario
Formulario de google forms https://docs.google.com/forms/d/e/1FAIpQLSfYyHOxj9HiPvgDpm4e4QaK-KA3dM1SS_z9t49oj9j6lJuWrw/viewform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 (https://docs.google.com/forms/d/e/1FAIpQLSfYyHOxj9HiPvgDpm4e4QaK-KA3dM1SS_z9t49oj9j6lJuWrw/viewform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)

Encuesta
Formulario de Google Forms: https://docs.google.com/forms/d/e/1FAIpQLSc_81NKNoITIvo-TaYY85rAkJE1Bv2__QJW4GEqIy2rwSXp9w/viewform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 (https://docs.google.com/forms/d/e/1FAIpQLSc_81NKNoITIvo-TaYY85rAkJE1Bv2__QJW4GEqIy2rwSXp9w/viewform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)

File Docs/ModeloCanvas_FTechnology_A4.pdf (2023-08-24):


Problemática a resolver

En la actualidad son con demasía los trabajos que requieren un mayor aporte presencial, por lo que la mayoría de la población salvadoreña invierte largos periodos de tiempo, muchas de estas personas involucradas han creado un lazo afectivo con sus fieles mascotas, brindándoles cariño y cuidados básicos que estos animales demanden. La responsabilidad, el compromiso, la lealtad y el amor incondicional forman parte de un vínculo afectivo que el dueño tiende a hacer con su mascota, por consecuencia se genera una empatía animal donde el individuo querrá brindarle cariño y cuidados básicos u específicos para el sano desarrollo y cuidado de su mascota.

En nuestro país existen muchas personas poseedoras de mascotas que pasan lejos de sus casas durante largos períodos de tiempo ya sea por factores académicos o laborales que demanden su presencia, por lo tanto, sus mascotas quedan solas en casa sin un control en su entrega diaria de alimento; debido a esto los dueños idean posibles soluciones como pedirle a un vecino o persona de confianza que pueda cuidarlo mientras no esté, cancelar o posponer salidas, dejar raciones dobles, etc., algunas de estas soluciones llegan a generar un desbalance en la ingesta de alimentos, por lo que, a largo plazo desarrollarían problemas de salud (vomito, sobrepeso, diarrea etc.), llegando a afectar así un desarrollo adecuado más, sin embargo, la mascota no es la única que tiene problemas en esta situación, al amo o dueño puede pasar por momentos de estrés o preocupación.

Propuesta de negocio

Un dispensador de comida conserva el alimento de la mascota en adecuadas condiciones es por esto que F Technology con su producto Croquette planea funcionar como un dispensador de comida para mascotas que ayudará al cliente a organizar y/o crear horarios de alimentación para su mascota de forma remota. Pero indagaremos más en esto continuación.

Muchas personas tienen mascotas, solo en El Salvador, el 65% de la población admite tener al menos una mascota (predominando perros y gatos); a su vez, dentro de este gran porcentaje de personas con mascotas se encuentra un grupo que no tiene tiempo (ya sea porque estudia, trabaja o realizaba ambas actividades) que dedicarles a sus mascotas, en especial a uno de los puntos más importantes del cuido de una “la alimentación”. De este problema ya se han intentado encargar otros productos como “Smell n Smile”, “Ferplast”, entre otros; pero todos estos fallan en algo, su funcionamiento, pues sirven comida de forma “constante” o tras presionar un botón colocado en el dispensador, por lo tanto, una persona que no se encuentra cerca de dicho dispositivo y por ende de su mascota, no puede llevar registro de las porciones que esta come.

Ahora la pregunto es, ¿cómo Croquette resuelve este problema? Bien, conocemos el problema y sabemos que no todas las mascotas son iguales o comen la misma cantidad de alimento, es por esto que nuestro producto funciona como un dispensador de comida, pero lo que caracteriza a Croquette es que no es un dispensador de comida cualquiera, Croquette permite al usuario programar la hora y tamaño de porción que se servirá y todo esto de forma remota, haciendo uso de una aplicación móvil llamada FTechnology que es amigable al usuario y realmente intuitiva, todo esto permite llevar control de la alimentación de la mascota.

El objetivo del producto no es solo ser comprado, sino funcionar como servicio; esto gracias a la aplicación móvil (indispensable para el uso del dispositivo), ¿por qué hablamos de un servicio? Bien, primero se debe saber que dentro de esta app se planea generar ingresos mediante publicidad, dicha publicidad podrá ser bloqueada por el usuario tras pagar una cuota mensual, trimestral o anual, además de que el simple hecho de poseer la aplicación le dará acceso a cualquier actualización de la misma. Así que el objetivo del producto es ser comprado, pero hacer que el usuario no se separe de la compañía.

Ahora bien, ¿cómo funciona Croquette? El dispensador de comida contará con una programación que permite al usuario plantear periodos de tiempo en los que la comida será depositada en el recipiente a través de una aplicación, asimismo el producto contará con un sensor en la parte inferior del plato de comida, este permitirá conocer si el plato está vacío o no; los materiales del dispensador son aluminio (el recipiente de comida) y plástico (la carcasa del producto).

Dicho esto, se realizaría de la siguiente manera:

- El dueño contará con una aplicación llamada “F Technology”, donde realizará las solicitudes de registro necesarias para su ingreso en dicha App.
- Al ingresar el usuario marcará los lapsos de tiempo y raciones en los que desea que se sirva la comida.
- Dicha información será transmitida vía wifi al Arduino incluido en el producto, que con la programación adecuada ejecutará cada una de las solicitudes propuestas.
- La comida será trasladada al recipiente por un tubo, el cual tendrá una compuerta que abrirá y cerrará con la información transmitida al servomotor.
- Cuando el recipiente de alimento este vacío, el Arduino emitirá un mensaje a través de la aplicación al usuario. Logrando que el ciclo de alimentación se efectúe de la misma manera planteada desde el punto 2.
- En el dado caso el sensor detecté que el recipiente aún no está vacío, se saltará hasta el siguiente horario para servir la ración de alimento y dejará un registro en la aplicación para avisar al usuario cuando se efectuó un salto de horario.

Para cerrar, Croquette es un producto que busca resolver una problemática que aqueja a un público muy amplio (como lo es el de personas con mascotas, pero poco tiempo libre) es por ello y porque sobresale y diferencia de otros muchos productos que buscan lo mismo, Croquette que es un producto viable para desarrollar y que no solo generara ingresos, sino ganancias.


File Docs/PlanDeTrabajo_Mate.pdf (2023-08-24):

# PLAN DE TRABAJO

F TECHNOLOGY

PERIODO

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
TAREAS

### 1. Buscar problemas en nuestra

realidad o entorno

### 2. Lluvia de ideas para crear

soluciones a los problemas encontrados haciendo uso de arduino y el uso de la impresora 3D

### 3. Escogiendo ideas y

analizarlas a fondo (aplicarles el FODA, el mapa de empatía y el PEST)

### 4. Creando ideas para el logo y

nombre del emprendimiento

### 5. Concretar a fondo cuales

son las funciones que queremos que el producto realice

### 6. Comenzar con la creación de

las primeras pantallas de la aplicación para el control del producto (SplashScreen, Login, Menú)

INICIO
23 febrero

26 febrero

03 marzo

13 marzo

17 marzo

25 marzo

FIN
25 febrero

02 marzo

10 marzo

16 marzo

24 marzo

30 marzo

# TRABAJO

F TECHNOLOGY

PERIODO
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
TAREAS

### 1. Probando ideas para carcasa del producto y para poner la ubicación de la placa de arduino

### 2. Hacer listado y presupuesto de materiales que se necesitan para crear la carcasa del producto 3. Empezar con la programación del producto por medio de

C++

### 4. Desarrollo más a fondo de la programación de las pantallas de la aplicación

INICIO

17 abril

03 mayo

16 mayo

02 junio

FIN

27 abril

15 mayo

30 mayo

20 junio

# TRABAJO

F TECHNOLOGY

PERIODO

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
TAREAS

### 1. Creación del primer prototipo y pruebas del mismo

### 2. Detectar posibles fallas e implementar el focus group para evaluar el segmento de mercado

### 3. Análisis de posibles mejoras a implementar basandose en las pruebas y en el focus group

### 4. Desarrollo más a fondo de la programación de las pantallas de la aplicación

INICIO

03 julio

18 julio

18 agosto

FIN

14 julio

07 agosto

17 agosto

31 agosto

09 agosto

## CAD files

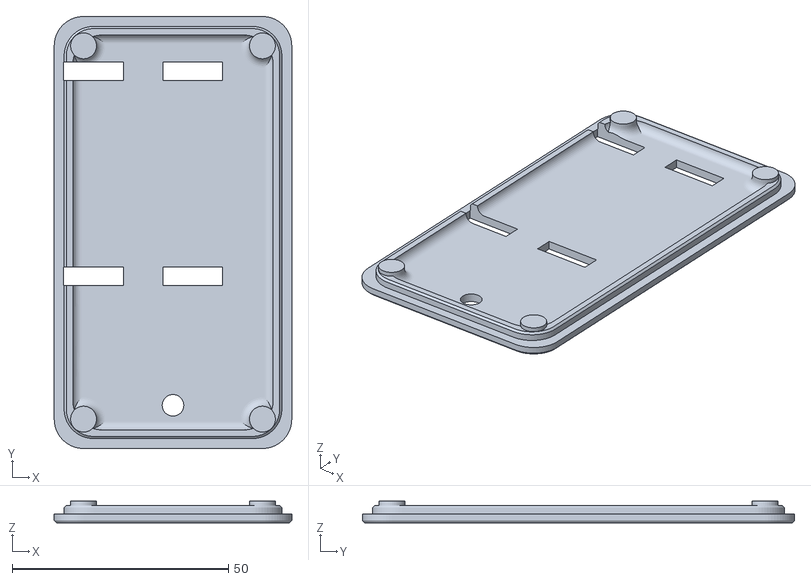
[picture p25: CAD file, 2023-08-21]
Croquette/designs.tls/UNO+PW_Top.stl
55.0 x 100.0 x 5.00

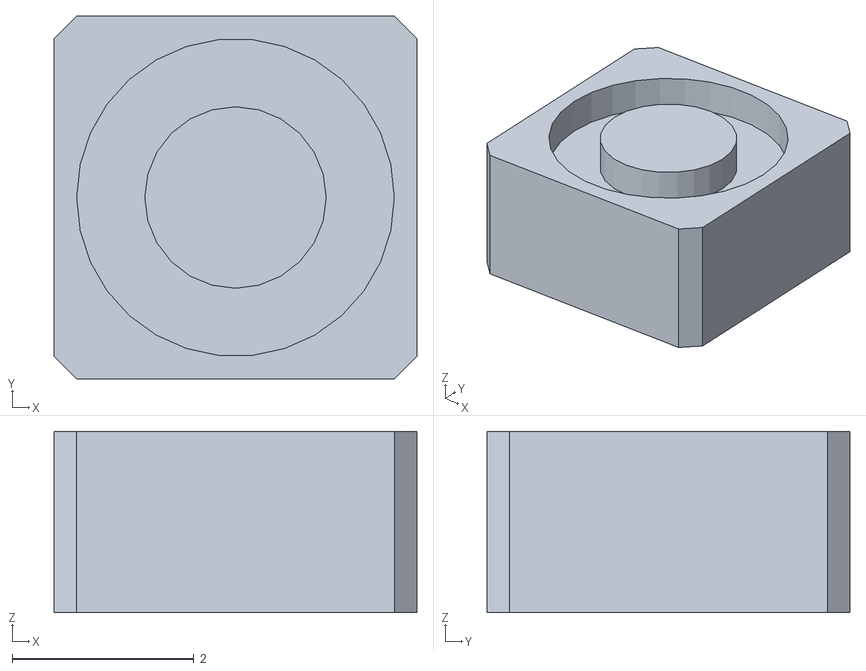
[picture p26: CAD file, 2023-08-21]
Croquette/designs.tls/Button_Ok.stl
4.00 x 4.00 x 2.00

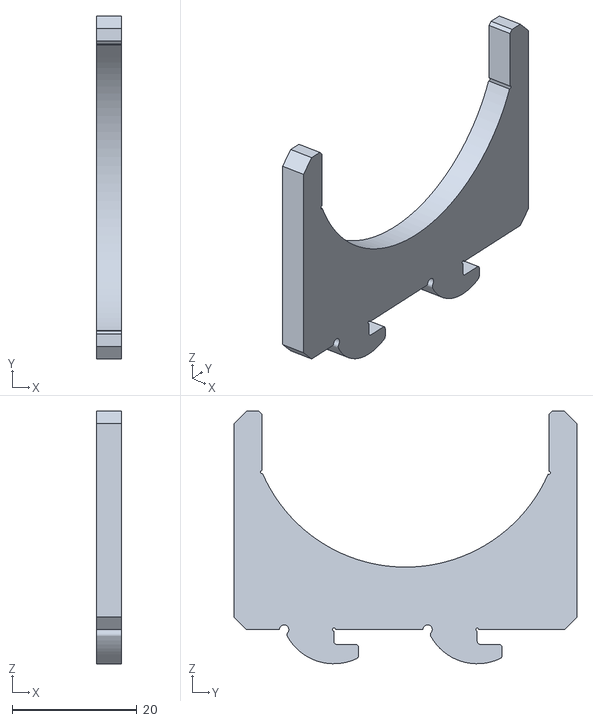
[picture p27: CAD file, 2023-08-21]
Croquette/designs.tls/Support_Feeder.stl
4.00 x 55.0 x 40.5

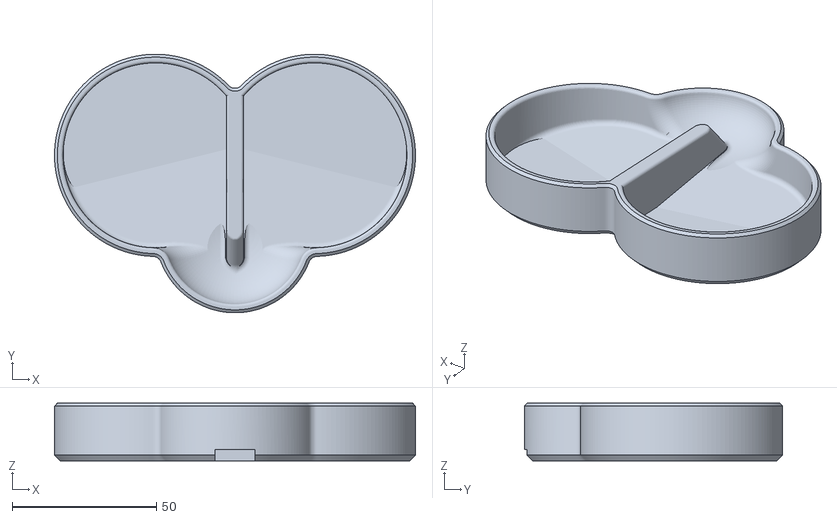
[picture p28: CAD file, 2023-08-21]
Croquette/designs.tls/Tray.stl
125.0 x 89.5 x 20.0

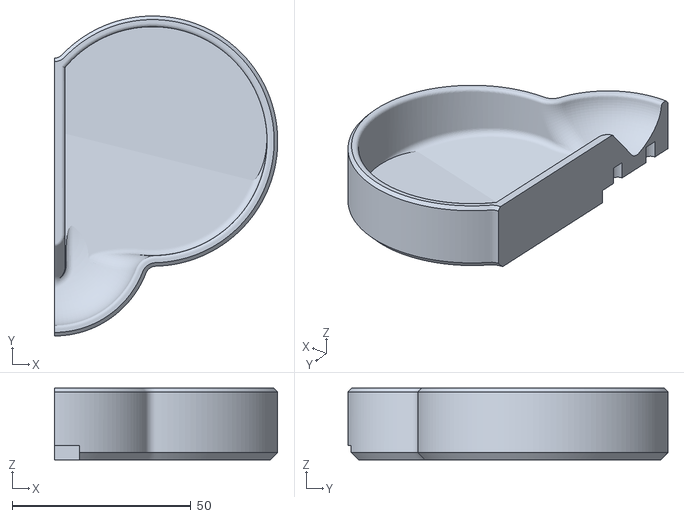
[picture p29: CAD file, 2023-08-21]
Croquette/designs.tls/Tray_Right.stl
62.5 x 89.5 x 20.0

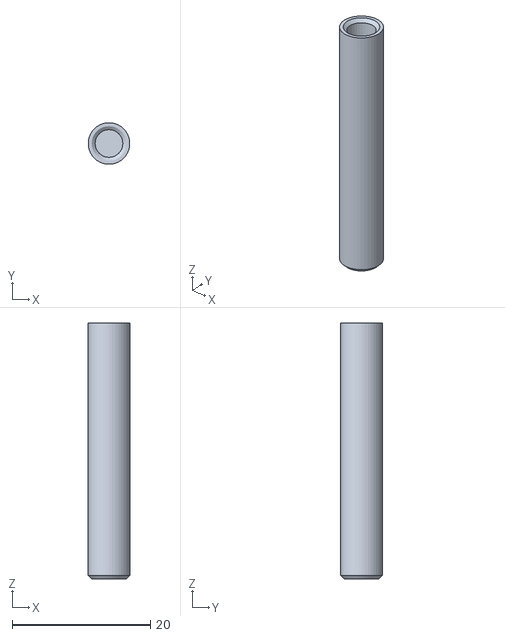
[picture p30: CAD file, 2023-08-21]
Croquette/designs.tls/Case_Cover_Leg.stl
6.00 x 6.00 x 37.0

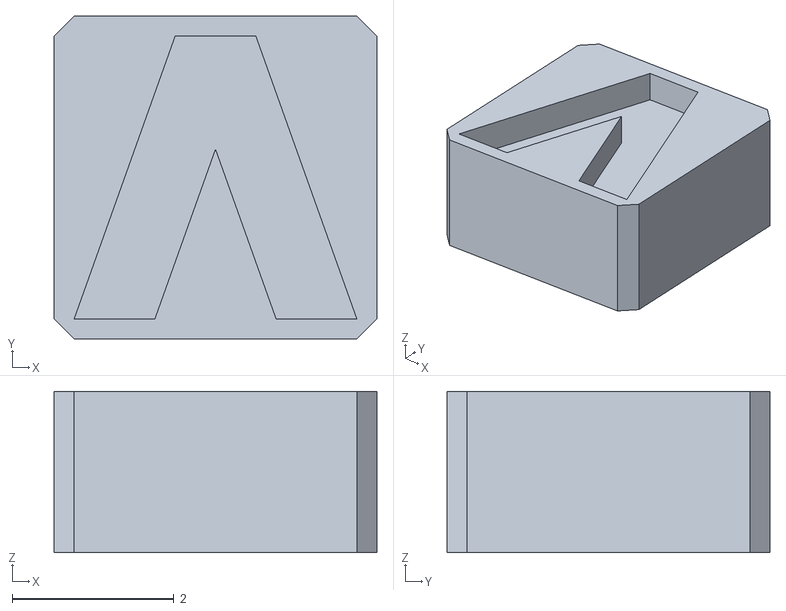
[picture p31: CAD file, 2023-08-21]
Croquette/designs.tls/Button_Up.stl
4.00 x 4.00 x 2.00

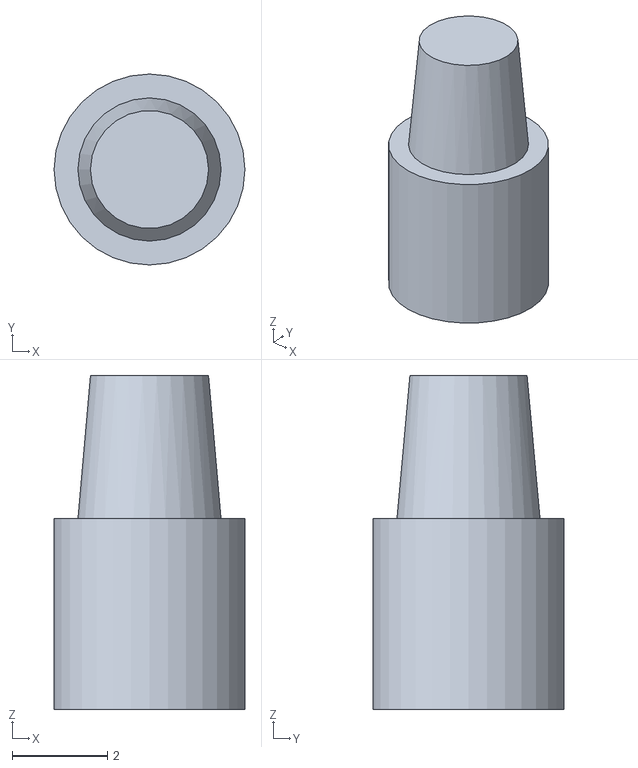
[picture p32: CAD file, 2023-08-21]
Croquette/designs.tls/LCD_Pin.stl
4.00 x 4.00 x 7.00

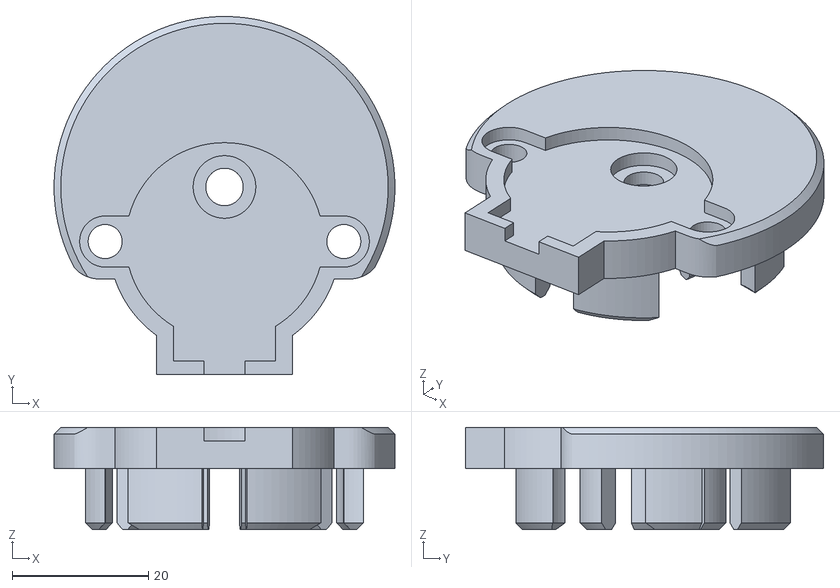
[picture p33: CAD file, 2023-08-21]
Croquette/designs.tls/Motor_plate.stl
50.0 x 52.5 x 15.0

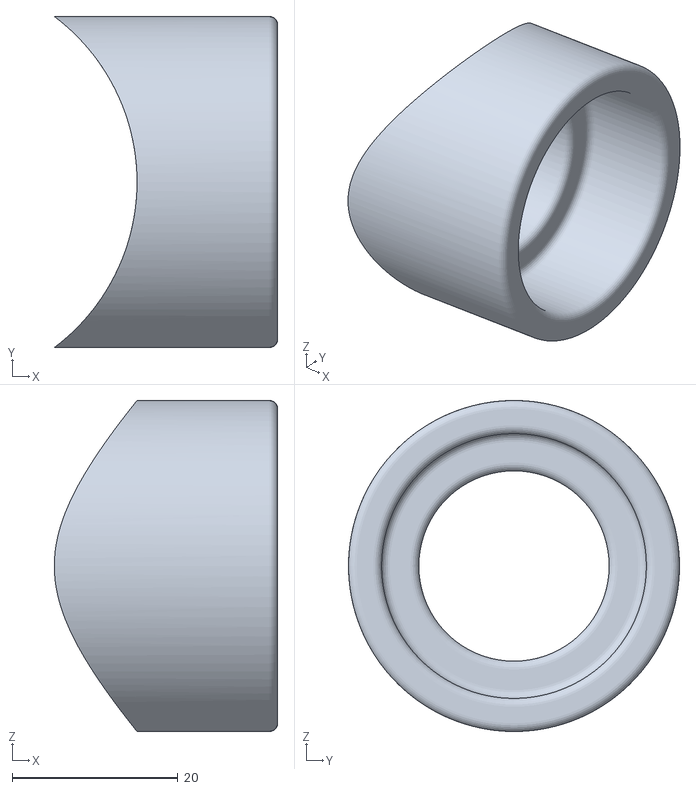
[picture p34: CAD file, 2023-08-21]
Croquette/designs.tls/Extruder_P2.stl
27.0 x 40.0 x 40.0

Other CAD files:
Croquette/designs.tls/Tray_Left.stl
Croquette/designs.blender/Button_Ok.blend
Croquette/designs.blender/Button_Up.blend
Croquette/designs.blender/Case_Cover_Leg.blend
Croquette/designs.blender/Extruder_P1.blend
Croquette/designs.blender/Extruder_P2.blend
Croquette/designs.blender/LCD_Pin.blend
Croquette/designs.blender/Motor_plate.blend
Croquette/designs.blender/Support_Feeder.blend
Croquette/designs.blender/Tray.blend
Croquette/designs.blender/Tray_Left.blend
Croquette/designs.blender/Tray_Right.blend
Croquette/designs.blender/UNO+PW_Case.blend
Croquette/designs.blender/UNO+PW_Top.blend
Croquette/designs.blender/Wormgear.blend
Croquette/designs.blender/Wormgear_long_pitch.blend
Croquette/designs.blender/Wormgear_short_pitch.blend

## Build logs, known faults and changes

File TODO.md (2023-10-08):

# Tareas Pendientes

1. **(LISTO)** *7 de octubre 2023*: **Terminar de programar el protocolo de comunicación de Croquette**: Finalizar la implementación del protocolo de comunicación para garantizar la interacción correcta entre el dispositivo Croquette y la aplicación.

2. **Programar el código para el Arduino (funcionamiento con la app, internet)**: Desarrollar el código que permitirá a Croquette funcionar en conjunto con la aplicación para la dispensación de alimentos a través de Internet.

3. **(LISTO)** *6 de octubre 2023*: **Soporte para Múltiples Croquettes**: Habilitar la capacidad para que los usuarios conecten varios dispositivos Croquette a la aplicación, mejorando la experiencia del usuario.

4. **(LISTO)** *5 de octubre 2023*: **Flujo de Compra de Croquette desde la Tienda**: Implementar la funcionalidad que permitirá a los usuarios realizar compras de productos Croquette directamente desde la aplicación, facilitando la adquisición de nuevos dispositivos.

5. **(LISTO)** *5 de octubre 2023*: **Acceso a la Tienda desde el Panel**: Agregar una sección que permita a los usuarios acceder a la tienda de productos Croquette desde el panel de control, brindándoles una experiencia completa. 

6. **(LISTO)** *8 de octubre 2023*: **Acceso a las Preguntas Frecuentes (FAQ) desde el Panel**: Incorporar un enlace que proporcione acceso rápido a las preguntas frecuentes (FAQ) desde el panel de control, mejorando la disponibilidad de información útil para los usuarios.

7. **Guía de Instalación**: Crear una sección que permita a los usuarios consultar una guía de instalación desde el panel de control, asegurando una configuración exitosa de Croquette.

8. **(LISTO)** *7 de octubre 2023*: **Crear una simulación de Croquette para pruebas**: Desarrollar una simulación de Croquette en Node.js para realizar pruebas exhaustivas y garantizar su correcto funcionamiento.

9. **Soldar el circuito**: Completar el ensamblaje del circuito de Croquette mediante el proceso de soldadura, asegurando una conexión sólida y confiable.

10. **Programar el código para el Arduino (funcionamiento sin app, localhost)**: Desarrollar el código que permitirá que Croquette funcione de forma independiente sin necesidad de la aplicación, brindando opciones de uso flexibles.

11. **Armar las piezas impresas de Croquette**: Ensamblar las partes impresas de Croquette para construir el dispositivo físico.

12. **Instalar el circuito de Croquette en las piezas**: Colocar el circuito de Croquette en las piezas impresas para completar la construcción del dispositivo.

13. **(LISTO)**: **Edición de Perfil de la Mascota**: Implementar la funcionalidad que permita a los usuarios editar los perfiles de sus mascotas para proporcionar una experiencia personalizada. 

# Problemas de Seguridad

- **Vulnerabilidad en la Edición del Perfil**:
  Descubrí una vulnerabilidad en la página de edición de perfiles en la fecha 2 de octubre de 2023. El problema radica en cómo se construyen las rutas para la edición de perfiles. Actualmente, se utiliza un formulario como el siguiente:

  ```html
  <form action="' . route('api/v1/auth/edit/profile/' . $profile->id . '/' . "name", false) . '" method="POST">
      <div class="form-group">
          '.TokenCsrf::getInput().'
          <label for="newName">Nuevo nombre</label>
          <input type="text" class="form-control" name="name">
      </div>
  </form>
  ```

  El problema principal es que el ID del usuario se transmite en texto plano en la URL del atributo action. Esto significa que cualquier persona podría editar y cambiar este ID, lo que permitiría hacerse pasar por otro usuario y modificar su nombre y los datos de su mascota.

  Esta vulnerabilidad tiene un alcance limitado, ya que solo permite editar el nombre y el avatar de un usuario, también es posible editar los datos de las mascotas. Por lo tanto, no implica un riesgo de robo de datos.

  Para solucionar este problema de seguridad, es mejor no enviar el ID del usuario a través de la URL. En lugar de depender del ID del usuario en la URL, se podría utilizar el token de autenticación. Este token se envía automáticamente a través de una cookie. Cuando el usuario hace clic en el botón y realiza la siguiente solicitud, se podría recuperar de manera segura el ID del usuario desde el token de autenticación. Esta forma es más segura y evita exponer información confidencial en la URL.

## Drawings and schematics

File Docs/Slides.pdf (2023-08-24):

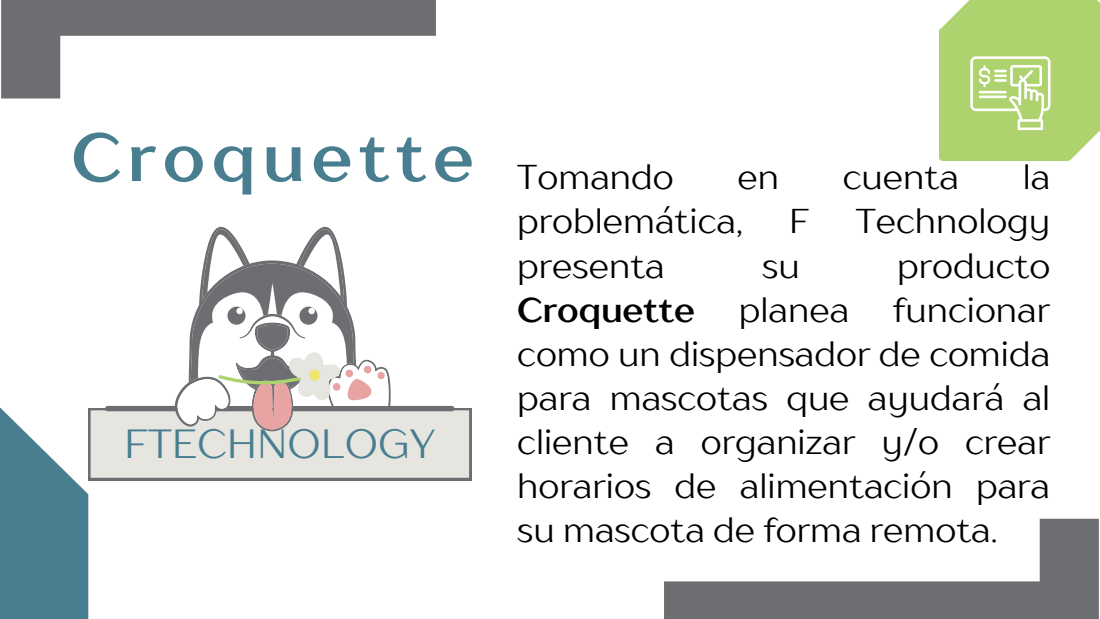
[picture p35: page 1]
FTECHNOLOGY; Croquette Tomando; cuenta; presenta; producto

problemática, F Technology
Croquette planea funcionar
como un dispensador de comida
para mascotas que ayudará al
cliente a organizar y/o crear
horarios de alimentación para
su mascota de forma remota.

### FTechnology

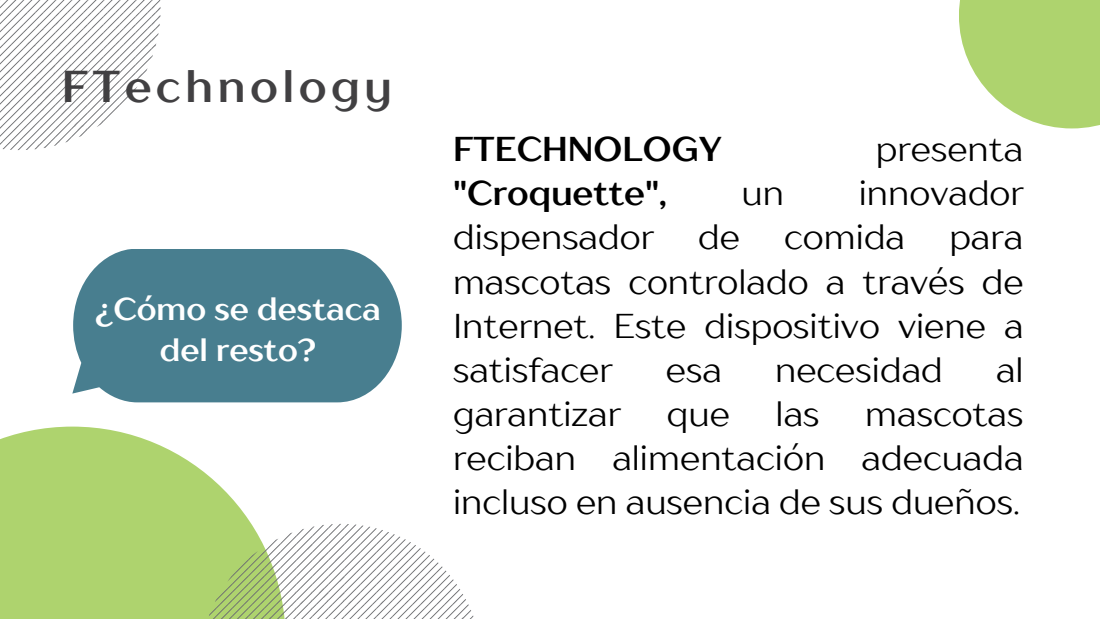
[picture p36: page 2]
FTECHNOLOGY; presenta; innovador; satisfacer; esa; necesidad

"Croquette"
dispensador de comida para
mascotas controlado a través de
Internet. Este dispositivo viene a
garantizar que las mascotas
reciban alimentación adecuada
incluso en ausencia de sus dueños.

¿Cómo se destaca
del resto?

### FTechnology

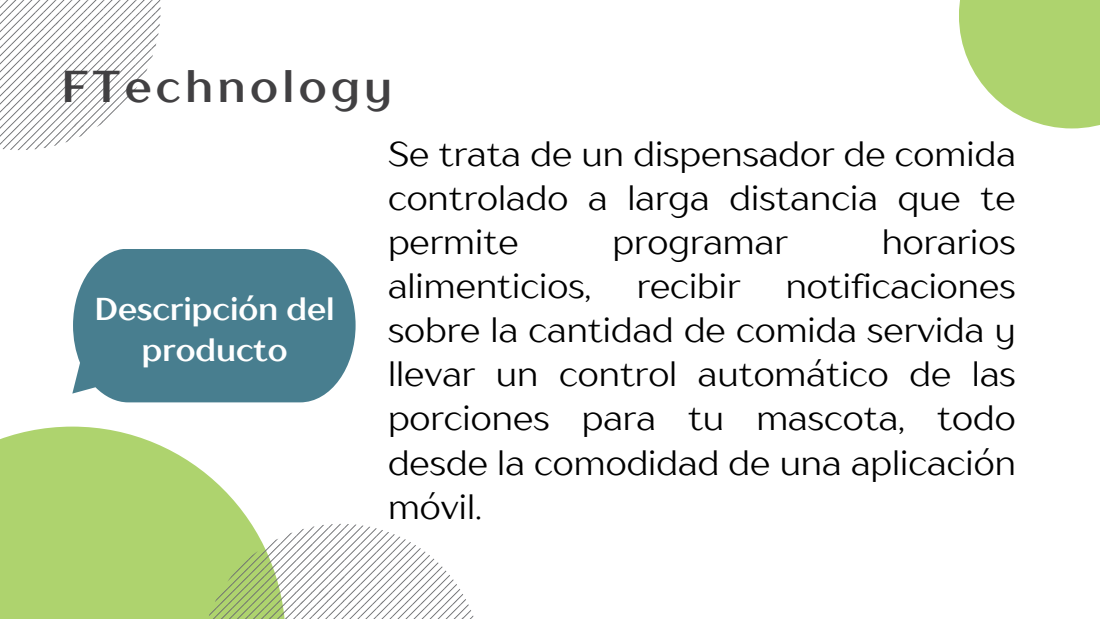
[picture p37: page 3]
permite; programar; horarios; Descripción del producto

Se trata de un dispensador de comida
controlado a larga distancia que te
alimenticios, recibir notificaciones
sobre la cantidad de comida servida y
llevar un control automático de las
porciones para tu mascota, todo
desde la comodidad de una aplicación
móvil.

### FTechnology

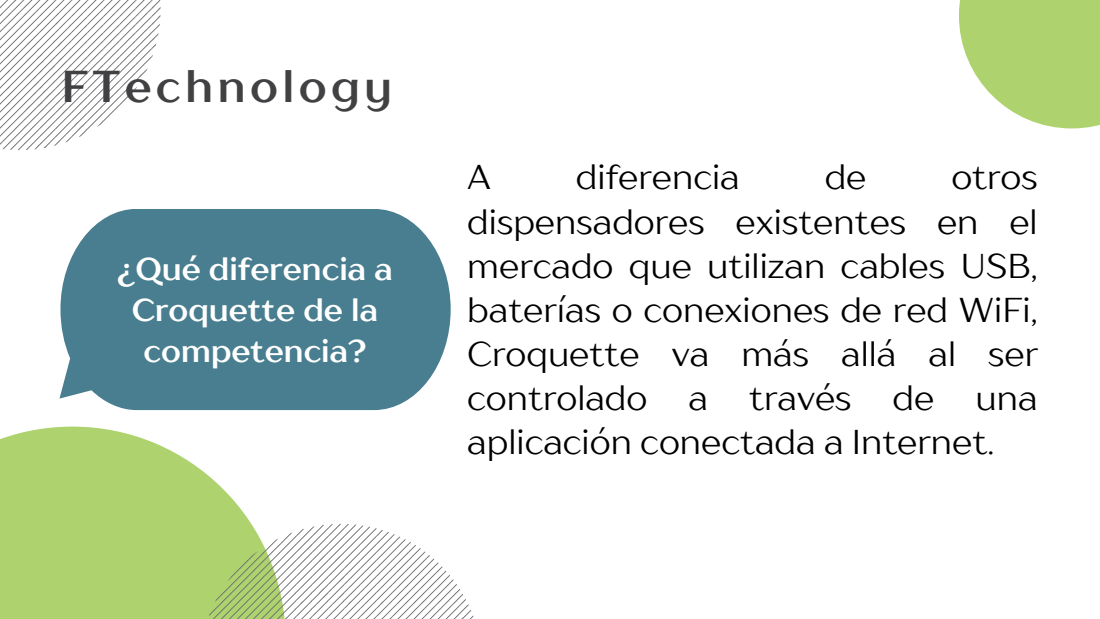
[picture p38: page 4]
diferencia; otros

dispensadores existentes en el
mercado que utilizan cables USB,
baterías o conexiones de red WiFi,
Croquette va más allá al ser
controlado a través de una
aplicación conectada a Internet.

¿Qué diferencia a
Croquette de la
competencia?

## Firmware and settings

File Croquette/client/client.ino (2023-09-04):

// CAT FEEDER
// v0.1

// LIBRARY
#include <Stepper.h>
#include <LiquidCrystal.h>
#include <HX711.h>

// VARIABLES & PINS

// Stepper Motor
#define STEPS 32                              // Number of steps per revolution of Internal shaft
int Steps2Take;                               // 2048 = 1 Revolution
const int X_Speed = 600;                      // Max 1100
const int In1 = 2, In2 = 4, In3 = 3, In4 = 5; // In1, In2, In3, In4 in the sequence 1-3-2-4
Stepper small_stepper(STEPS, In1, In2, In3, In4);

// Buttons
const int S_pin = 6; // SCROLL digital pin connected to switch output
const int E_pin = 7; // ENTER digital pin connected to switch output
int S_state = 0;
int E_state = 0;

// LCD Display
const int rs = 12, en = 13, d4 = 8, d5 = 9, d6 = 10, d7 = 11;
const int backlightPin = A5; // Output to control backlight with pin 15 of the display.
LiquidCrystal lcd(rs, en, d4, d5, d6, d7);

// Load Cell
HX711 scale;
const int DTPin = A0, SCKPin = A1;
const int scale_factor = 420.0983; // Scale factor following calibration with a known weight.
float Weight;                      // Weight measurement. Compared to value in grams.

// Parameters
int Qty_Weight = 45;            // Default value for food to be delivered. In grams.
int Cust_Qty_Weight = 0;        // Minimum custom value.
int InterV = 5;                 // Default value for interval between deliveries. In hours.
int Cust_InterV = 0;            // Minimum custom value.
int Sel_Line = 0;               // Menu line selection.
int Delaystart = 0;             // Default value for delayed start. In hours.
unsigned long Start_MTimer = 0; // Motor timer. Store time last time motor was started.
unsigned long Stop_MTimer = 0;  // Motor timer. Store time last time motor was stoped.
const int MTimerErr = 30;       // Motor timout. In seconds.

// CODE

void setup()
{
  Serial.begin(9600);

  pinMode(S_pin, INPUT_PULLUP);
  pinMode(E_pin, INPUT_PULLUP);
  pinMode(backlightPin, OUTPUT);
  pinMode(DTPin, INPUT);
  pinMode(SCKPin, INPUT);

  scale.begin(DTPin, SCKPin);
  scale.set_scale(scale_factor);
  scale.tare();

  lcd.begin(16, 2);
  digitalWrite(backlightPin, HIGH);
  lcd.print("Croquette - FTecnology");
  delay(1000);
  lcd.clear();
  delay(500);

/* 
  Esto es un menu, es para definir que modo se va a eligir
  existen dos modos: Default y Custom

  

 */
Mainmenu:
  lcd.setCursor(0, 0);
  lcd.print(">");
  lcd.setCursor(1, 0);
  lcd.print("Default:");
  lcd.print(Qty_Weight);
  lcd.print("g,");
  lcd.print(InterV);
  lcd.print("hr");
  lcd.setCursor(1, 1);
  lcd.print("Custom:");

  do // Loop to select Default or Custom values
  {
    S_state = digitalRead(S_pin);
    E_state = digitalRead(E_pin);
    if (S_state == LOW)
    {
      lcd.setCursor(0, Sel_Line);
      lcd.print(" ");
      if (Sel_Line == 0)
        Sel_Line = Sel_Line + 1;
      else
        Sel_Line = Sel_Line - 1;
      lcd.setCursor(0, Sel_Line);
      lcd.print(">");
      delay(300);
    }
  } while (E_state == HIGH);
  delay(300);


  if (Sel_Line == 0) //Esto si se define el deafult
    goto Endsetup;
  if (Sel_Line == 1){  //Esto pasa solamente si se define Custom
    lcd.clear(); // Loop to define Custom weight
    lcd.setCursor(1, 0);
    lcd.print("Cantidad:");
    lcd.setCursor(1, 1);
    lcd.print(Cust_Qty_Weight);
    lcd.print(" g");

    do
    {
      S_state = digitalRead(S_pin);
      E_state = digitalRead(E_pin);
      if (S_state == LOW)
      {
        if (Cust_Qty_Weight < 95)
          Cust_Qty_Weight = Cust_Qty_Weight + 5;
        else
          Cust_Qty_Weight = 5;
        lcd.setCursor(1, 1);
        lcd.print("  ");
        lcd.setCursor(1, 1);
        lcd.print(Cust_Qty_Weight);
        Qty_Weight = Cust_Qty_Weight;
        delay(300);
      }
    } while (E_state == HIGH);
    delay(300);

    lcd.clear(); // Loop to define Custom interval
    lcd.setCursor(1, 0);
    lcd.print("Feed Interval:");
    lcd.setCursor(1, 1);
    lcd.print(Cust_InterV);
    lcd.print(" hr");

    do
    {
      S_state = digitalRead(S_pin);
      E_state = digitalRead(E_pin);
      if (S_state == LOW)
      {
        if (Cust_InterV < 23)
          Cust_InterV = Cust_InterV + 1;
        else
          Cust_InterV = 1;
        lcd.setCursor(1, 1);
        lcd.print("  ");
        lcd.setCursor(1, 1);
        lcd.print(Cust_InterV);
        InterV = Cust_InterV;
        delay(300);
      }
    } while (E_state == HIGH);
    delay(300);

    Sel_Line = 0;
    goto Mainmenu;
  }

Endsetup:
  lcd.clear(); // Loop to define delayed start value
  lcd.setCursor(0, 0);
  lcd.print("Delay to start:");
  lcd.setCursor(1, 1);
  lcd.print(Delaystart);
  lcd.print(" hr");

  do
  {
    S_state = digitalRead(S_pin);
    E_state = digitalRead(E_pin);
    if (S_state == LOW)
    {
      if (Delaystart < 24)
        Delaystart = Delaystart + 1;
      else
        Delaystart = 0;
      lcd.setCursor(1, 1);
      lcd.print("  ");
      lcd.setCursor(1, 1);
      lcd.print(Delaystart);
      delay(300);
    }
  } while (E_state == HIGH);
  delay(300);

  lcd.clear();
  lcd.setCursor(0, 0);
  lcd.print("Miam!");
  delay(1000);
  lcd.noDisplay();
  digitalWrite(backlightPin, LOW);
  delay(Delaystart * 1000); // Convert delay start from Hours to Millis

} // END SETUP

void loop()
{
  Start_MTimer = millis() / 1000;

FeedLoop: // Motor actuation at specified intervals. Stops when specified weight reached. Move forward and backward to prevent jamming

  for (int x = 0; x < 4; x++)
  {
    Steps2Take = 500;
    small_stepper.setSpeed(X_Speed);
    small_stepper.step(Steps2Take);
    Weight = scale.get_units();
    Stop_MTimer = millis() / 1000;
    Serial.print("Measure: ");
    Serial.println(Weight);
    Serial.print("Motor Time: ");
    Serial.println(Stop_MTimer - Start_MTimer);
    if (Weight > Qty_Weight)
      goto FeedComplete;
    if (Stop_MTimer - Start_MTimer > MTimerErr)
      goto FeedError;
  }

  delay(500);

  Steps2Take = -500;
  small_stepper.setSpeed(X_Speed);
  small_stepper.step(Steps2Take);

  delay(500);

  goto FeedLoop;

FeedError:                // Routine when the motor time-out. Call for user
  digitalWrite(In1, LOW); // Shutting off stepper motor
  digitalWrite(In2, LOW);
  digitalWrite(In3, LOW);
  digitalWrite(In4, LOW);
  lcd.display();
  lcd.clear();
  lcd.setCursor(5, 0);
  lcd.print("ERROR");

  E_state = digitalRead(E_pin); // Flash backlight until press OK button
  while (E_state == HIGH)
  {
    for (int light_on = 0; light_on < 501; light_on++)
    {
      E_state = digitalRead(E_pin);
      if (E_state == LOW)
        break;
      digitalWrite(backlightPin, HIGH);
      delay(1);
    }

    for (int light_off = 0; light_off < 501; light_off++)
    {
      E_state = digitalRead(E_pin);
      if (E_state == LOW)
        break;
      digitalWrite(backlightPin, LOW);
      delay(1);
    }
  }
  delay(300);

  lcd.clear();
  digitalWrite(backlightPin, HIGH);
  lcd.setCursor(0, 0);
  lcd.print("Feeding error");
  lcd.setCursor(0, 1);
  lcd.print("Refill&Press OK");

  E_state = digitalRead(E_pin); // Second user acknowledgement to resume the feed
  while (E_state == HIGH)
  {
    E_state = digitalRead(E_pin);
  }
  delay(300);

  lcd.clear();
  lcd.noDisplay();
  digitalWrite(backlightPin, LOW);
  Start_MTimer = millis() / 1000; // Reset motor timer
  goto FeedLoop;

FeedComplete:
  Serial.print("Complete");
  digitalWrite(In1, LOW); // Shutting off stepper motor
  digitalWrite(In2, LOW);
  digitalWrite(In3, LOW);
  digitalWrite(In4, LOW);

  delay(InterV * 1000); // Wait until next interval (in hour) until next loop

} // END LOOP

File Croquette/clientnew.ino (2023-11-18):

#include <Stepper.h>
#include <Wire.h>
#include <LiquidCrystal_I2C.h>
#include <HX711.h>

// Define constants for pins
const int In1 = 2, In2 = 4, In3 = 3, In4 = 5;
const int S_pin = 6;
const int E_pin = 7;
const int DTPin = A0, SCKPin = A1;

// Stepper motor configuration
const int STEPS = 32;
const int X_Speed = 600;
Stepper small_stepper(STEPS, In1, In2, In3, In4);

// LCD configuration
LiquidCrystal_I2C lcd(0x27, 16, 2);

// Load cell configuration
HX711 scale;
const float scale_factor = 420.0983;
float Weight;
int Qty_Weight = 45;
int Cust_Qty_Weight = 0;
int InterV = 5;
int Cust_InterV = 0;
int Sel_Line = 0;
int Delaystart = 0;
unsigned long Start_MTimer = 0;
unsigned long Stop_MTimer = 0;
const int MTimerErr = 30;

void setup() {
  Serial.begin(9600);
  pinMode(S_pin, INPUT_PULLUP);
  pinMode(E_pin, INPUT_PULLUP);
  Wire.begin();

  lcd.init();
  lcd.backlight();

  scale.begin(DTPin, SCKPin);
  scale.set_scale(scale_factor);
  scale.tare();

  lcd.clear();
  lcd.print("Croquette - FTecnology");
  delay(3000);
  lcd.clear();
  delay(500);

  // Display cat ASCII art
  lcd.setCursor(0, 0);
  lcd.print(" /\\_/\\ ");
  lcd.setCursor(0, 1);
  lcd.print("( o.o )");
  delay(3000);

  setupMainMenu();
}

void setupMainMenu() {
  lcd.clear();
  lcd.setCursor(0, 0);
  lcd.print(">");
  lcd.setCursor(1, 0);
  lcd.print("Default:");
  lcd.print(Qty_Weight);
  lcd.print("g,");
  lcd.print(InterV);
  lcd.print("hr");
  lcd.setCursor(1, 1);
  lcd.print("Custom:");

  while (digitalRead(E_pin) == HIGH) {
    int buttonState = digitalRead(S_pin);
    if (buttonState == LOW) {
      Sel_Line = 1 - Sel_Line;
      lcd.setCursor(0, Sel_Line);
      lcd.print(">");
      delay(300);
    }
  }

  delay(300);

  if (Sel_Line == 0) {
    // Default settings
    goto endSetup;
  } else if (Sel_Line == 1) {
    setupCustomSettings();
  }

endSetup:
  lcd.clear();
  lcd.setCursor(0, 0);
  lcd.print("Miam!");
  delay(1000);
  lcd.noBacklight();
  delay(Delaystart * 1000);
}

void setupCustomSettings() {
  lcd.clear();
  lcd.setCursor(1, 0);
  lcd.print("Quantity:");
  lcd.setCursor(1, 1);
  lcd.print(Cust_Qty_Weight);
  lcd.print(" g");

  while (digitalRead(E_pin) == HIGH) {
    int buttonState = digitalRead(S_pin);
    if (buttonState == LOW) {
      Cust_Qty_Weight = (Cust_Qty_Weight < 95) ? Cust_Qty_Weight + 5 : 5;
      lcd.setCursor(1, 1);
      lcd.print("  ");
      lcd.setCursor(1, 1);
      lcd.print(Cust_Qty_Weight);
      Qty_Weight = Cust_Qty_Weight;
      delay(300);
    }
  }

  delay(300);

  lcd.clear();
  lcd.setCursor(1, 0);
  lcd.print("Feed Interval:");
  lcd.setCursor(1, 1);
  lcd.print(Cust_InterV);
  lcd.print(" hr");

  while (digitalRead(E_pin) == HIGH) {
    int buttonState = digitalRead(S_pin);
    if (buttonState == LOW) {
      Cust_InterV = (Cust_InterV < 23) ? Cust_InterV + 1 : 1;
      lcd.setCursor(1, 1);
      lcd.print("  ");
      lcd.setCursor(1, 1);
      lcd.print(Cust_InterV);
      InterV = Cust_InterV;
      delay(300);
    }
  }

  delay(300);
  Sel_Line = 0;
  setupMainMenu();
}

void loop() {
  Start_MTimer = millis() / 1000;
  FeedLoop();

FeedComplete:
  Serial.print("Complete");
  digitalWrite(In1, LOW);
  digitalWrite(In2, LOW);
  digitalWrite(In3, LOW);
  digitalWrite(In4, LOW);

  delay(InterV * 1000);
}

void FeedLoop() {
  for (int x = 0; x < 4; x++) {
    int Steps2Take = 500;
    small_stepper.setSpeed(X_Speed);
    small_stepper.step(Steps2Take);
    Weight = scale.get_units();
    Stop_MTimer = millis() / 1000;
    Serial.print("Measure: ");
    Serial.println(Weight);
    Serial.print("Motor Time: ");
    Serial.println(Stop_MTimer - Start_MTimer);
    if (Weight > Qty_Weight) {
      goto FeedComplete;
    }
    if (Stop_MTimer - Start_MTimer > MTimerErr) {
      goto FeedError;
    }
  }

  delay(500);

  Steps2Take = -500;
  small_stepper.setSpeed(X_Speed);
  small_stepper.step(Steps2Take);

  delay(500);
  goto FeedLoop;
}

void FeedError() {
  digitalWrite(In1, LOW);
  digitalWrite(In2, LOW);
  digitalWrite(In3, LOW);
  digitalWrite(In4, LOW);
  lcd.backlight();
  lcd.clear();
  lcd.setCursor(5, 0);
  lcd.print("ERROR");

  int E_state = digitalRead(E_pin);
  while (E_state == HIGH) {
    for (int light_on = 0; light_on < 501; light_on++) {
      E_state = digitalRead(E_pin);
      if (E_state == LOW) {
        break;
      }
      lcd.backlight();
      delay(1);
    }

    for (int light_off = 0; light_off < 501; light_off++) {
      E_state = digitalRead(E_pin);
      if (E_state == LOW) {
        break;
      }
      lcd.noBacklight();
      delay(1);
    }
  }
  delay(300);

  lcd.backlight();
  lcd.setCursor(0, 0);
  lcd.print("Feeding error");
  lcd.setCursor(0, 1);
  lcd.print("Refill & Press OK");

  int E_state = digitalRead(E_pin);
  while (E_state == HIGH) {
    E_state = digitalRead(E_pin);
  }
  delay(300);

  lcd.noBacklight();
  Start_MTimer = millis() / 1000;
  FeedLoop();
}

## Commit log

2023-08-21 Add images and desings in tls files
    [Button_Ok.stl, Button_Up.stl, Case_Cover_Leg.stl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]
2023-08-21 Add files in .blender
    [Button_Ok.blend, Button_Up.blend, Case_Cover_Leg.blend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]
2023-08-24 Add docs, update README
    [Button_Ok.blend, Button_Ok.stl, Button_Up.blend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]
2023-09-16 Testing sockets winth node.js
2023-10-05 Implement product purchasing flow and add access to the store from the user panel
2023-10-06 Add support for multiple Croquettes devices
2023-10-08 Update Croquette channel communication protocol: Add utility file and command processor, as well as update the TCP server. Also, update the flow; now, the message type for communication is JSON.
